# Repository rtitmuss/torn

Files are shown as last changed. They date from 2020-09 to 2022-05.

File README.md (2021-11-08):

Torn
===============

The split keyboard kit made with through hole components. The design has been inspired by the [Corne](https://github.com/foostan/crkbd), [Plaid](https://github.com/hsgw/plaid) and [Discipline](https://github.com/coseyfannitutti/discipline) keyboards.

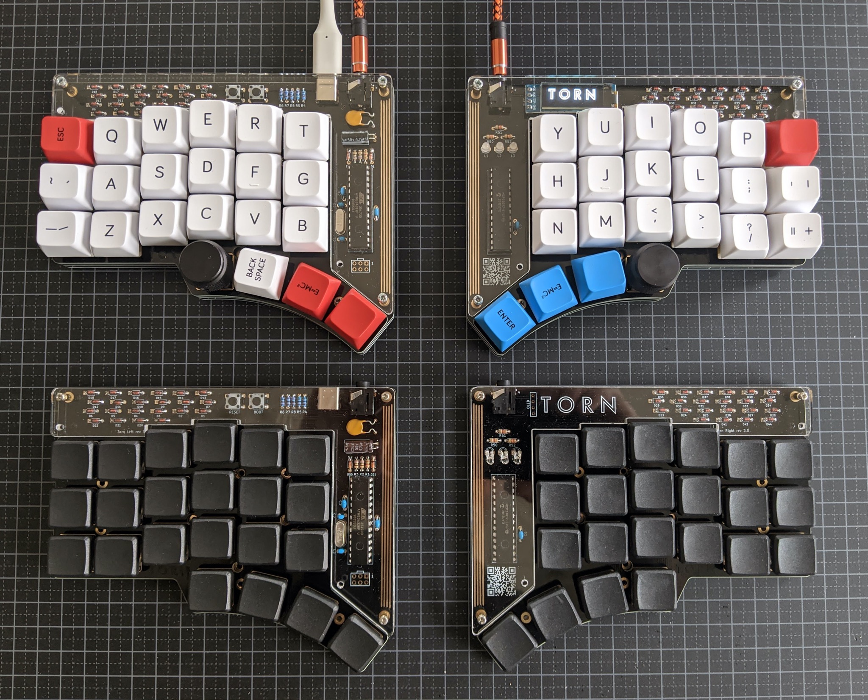
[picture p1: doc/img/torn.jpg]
torn


Torn uses an Atmega328P cpu, running QMK with VUSB:
- [QMK firmware](https://github.com/qmk/qmk_firmware/blob/master/keyboards/torn/readme.md).
- [Bootloader](https://github.com/rtitmuss/USBaspLoader).
- Compatible with [VIA](https://caniusevia.com/)

## Building your own Torn keyboard

Later this year you will be able to buy a Torn keyboard kit from [splitkb.com](https://blog.splitkb.com/blog/january-2021).
Alternatively you can also buy [all the parts](./doc/bom.md) needed youself.

Instructions are in the [Build guide](./doc/build.md) and [Troubleshooting guide](./doc/troubleshoot.md).
You can ask questions and get help on the [Torn Discord channel](https://discord.gg/mamAqNccju).

There is also a detailed [build log](https://github.com/rafaeldelboni/buildlogs/blob/main/torn-v3.md)
and [video](https://www.youtube.com/watch?v=7WUTQ30Datw). Thanks [rafaeldelboni](https://github.com/rafaeldelboni)! 

## Thanks

It would not have been possible for me to design Torn without the information and designs published by the mechanical keyboard community. So thanks go to ...

### Guides

* [Corne Keyboard build log](https://thomasbaart.nl/2018/11/26/corne-keyboard-helidox-build-log/) was my first step into this rabbit hole ...
* [Keyboard PCB Guide](https://github.com/ruiqimao/keyboard-pcb-guide) a beginners guide to designing a keyboard PCB in KiCad
* [Guide: Keyboard Construction Explained](https://brianlee.blog/2018/11/23/guide-keyboard-construction-explained/)
* [Cheat sheet: Custom keyboard mounting styles](https://thomasbaart.nl/2019/04/07/cheat-sheet-custom-keyboard-mounting-styles/)

### PCB Design

* [KiCad](https://kicad.org/) for PCB design
* [Split keyboard comparison site](https://jhelvy.shinyapps.io/splitkbcompare/) to iterate on key layout
* [Keyboard layout editor](http://www.keyboard-layout-editor.com/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,%3B&@_y:-0.875&x:2%3B&=X&_x:1%3B&=V&_x:5%3B&=M&_x:1%3B&=.%3B&@_y:-0.875&x:5%3B&=B&_x:3%3B&=N%3B&@_y:-0.875&a:7%3B&=&_a:4%3B&=Z&_x:11&a:7%3B&=&=%3B&@_y:-0.2749999999999999&x:3%3B&=&_x:7%3B&=%3B&@_r:13&rx:3.5&ry:8.5&y:-5.4&x:-0.5%3B&=%3B&@_r:26&y:-1&x:-0.5%3B&=%3B&@_r:39&y:-1&x:-0.5%3B&=%3B&@_r:-39&rx:11.5&y:-5.4&x:-0.5%3B&=%3B&@_r:-26&y:-1&x:-0.5%3B&=%3B&@_r:-13&y:-1&x:-0.5%3B&=) for your layout
* [Plate & Case Builder](http://builder.swillkb.com/) Generate CAD files from KLE files
* [keyswitches.pretty](https://github.com/daprice/keyswitches.pretty) KiCad library of mechanical keyboard switch footprints 

### QMK Firmware

* [QMK](https://docs.qmk.fm/#/) Quantum Mechanical Keyboard firmware
* [REMAP](https://remap-keys.app/) to easily configure your keyboard online
* [VIA](https://caniusevia.com/) to configure your keyboard

### 3d Design

The following are great resources to get started with keyboard case design:

* [Fusion 360](https://www.autodesk.com/products/fusion-360/personal)
* [65% Keyboard Case Design](https://youtu.be/4P0zfLLblOw)
* [Hinged Box for 3D Printing](https://youtu.be/iSBsBTMsGTk)
* [Snap Fit Cases](https://www.youtube.com/watch?v=E0NVC8xhf3I)
* [Knurling for 3D Printing](https://www.youtube.com/watch?v=jKPbye0XtMk)

### Other Keyboards

I took inspiration from other keyboards I'd used or liked:

* [Kinesis Advantage](https://kinesis-ergo.com/shop/advantage2/) my daily driver and endgame for almost 20 years! Opps! 
* [Corne](https://github.com/foostan/crkbd)
* [Discipline](https://github.com/coseyfannitutti/discipline) (used with permission from [coseyfannitutti](https://github.com/coseyfannitutti/))
* [Plaid](https://github.com/hsgw/plaid)
* [Lily](https://docs-gitbook.keeb.io/docs/iris-rev3-build-guide)
* [Dactyl](https://raw.githubusercontent.com/adereth/dactyl-keyboard/master/guide/circuit-diagram.png)

## License



The Torn Keyboard is licensed under [Creative Commons Attribution-NonCommercial 4.0 International License](https://creativecommons.org/licenses/by-nc/4.0).

This PCB design may be freely reproduced, modified, and manufactured for personal use only. If you would like to use this design commercially please contact me at richard.titmuss@gmail.com to request permission.
 
## Gallery

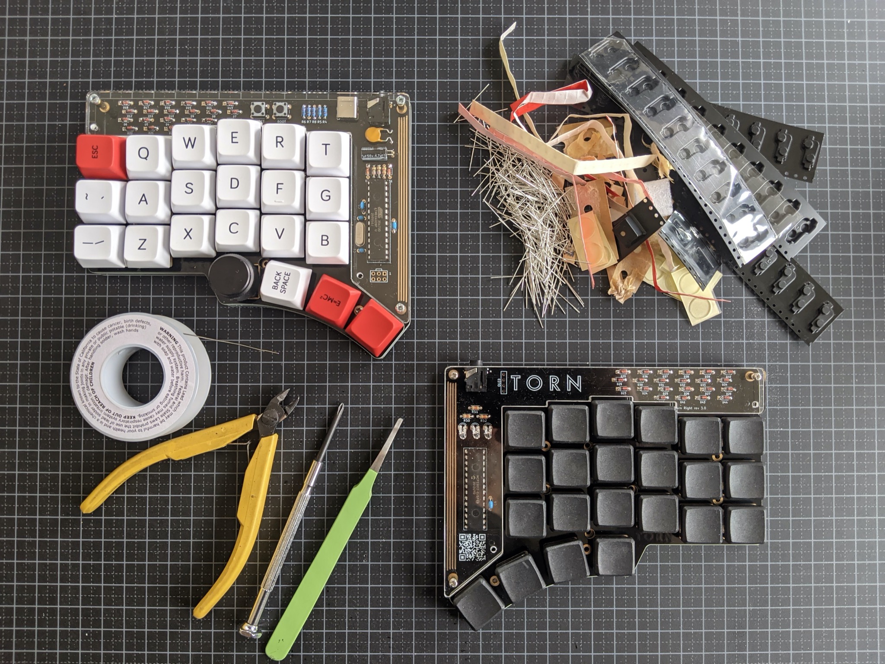
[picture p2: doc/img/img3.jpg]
Build Photo


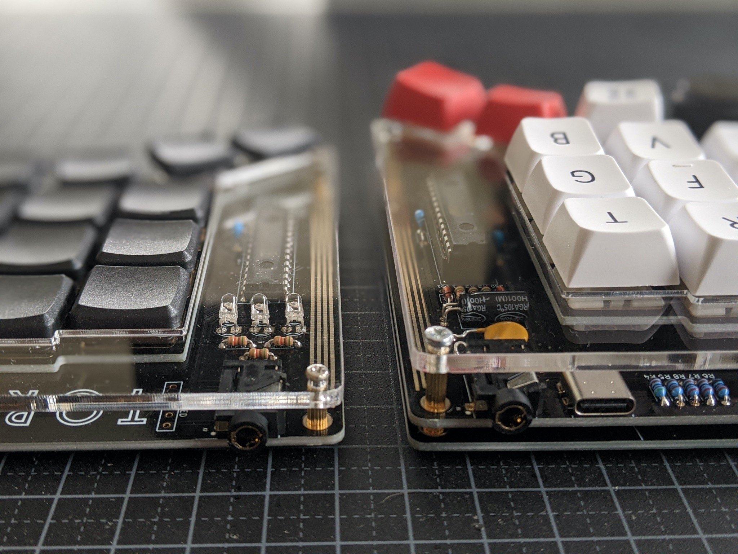
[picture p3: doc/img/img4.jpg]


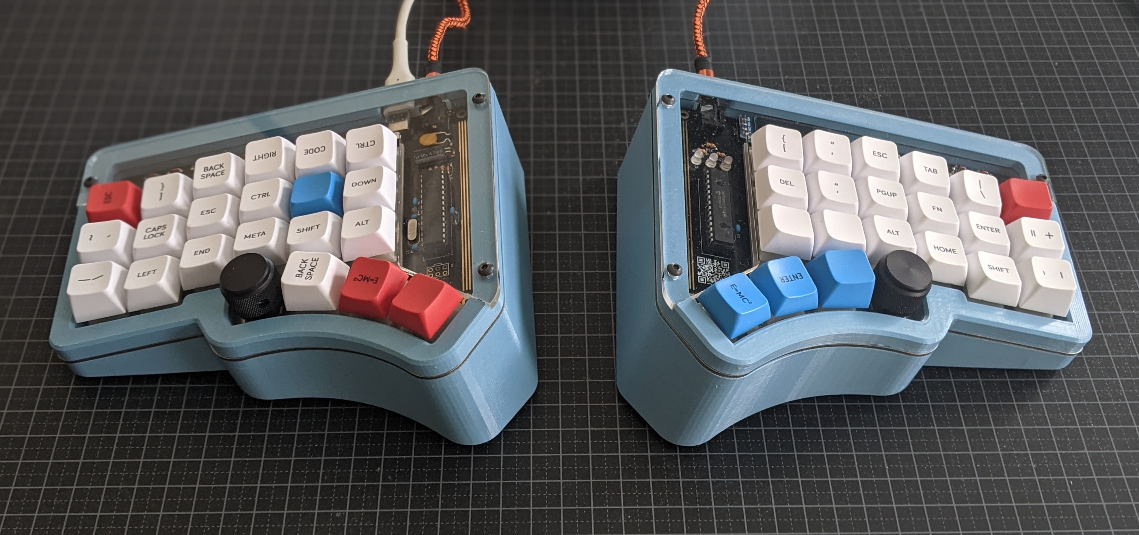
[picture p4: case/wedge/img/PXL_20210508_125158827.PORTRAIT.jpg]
Wedge Case


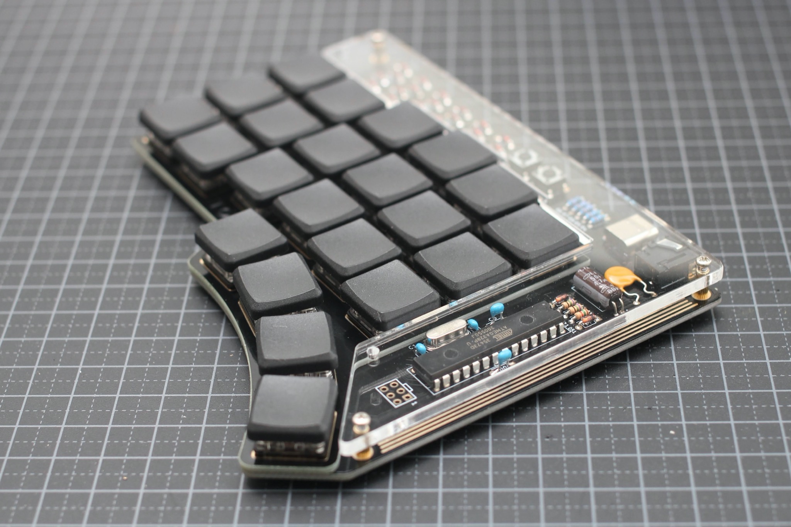
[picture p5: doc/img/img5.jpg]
Choc Switches


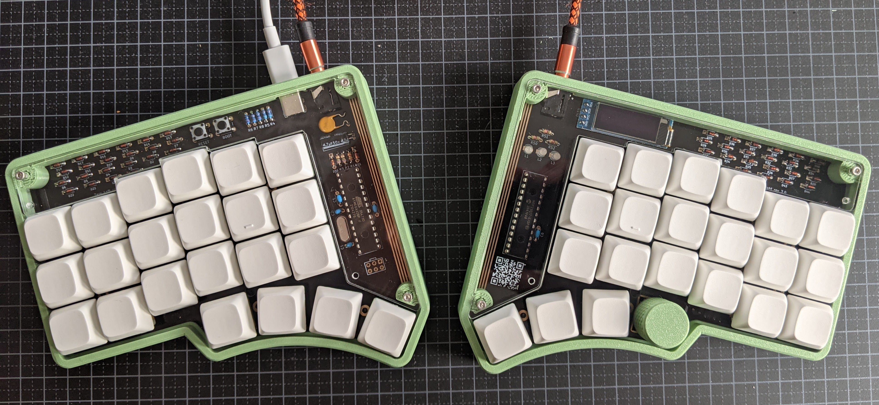
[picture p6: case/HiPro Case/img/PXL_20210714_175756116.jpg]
HiPro Case


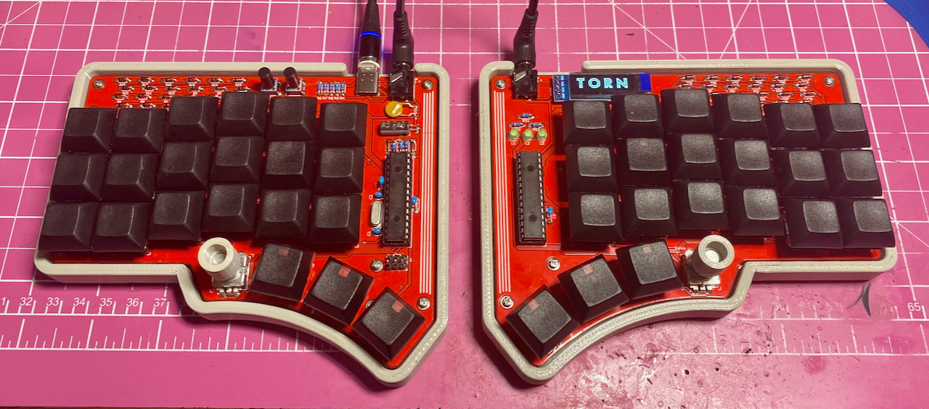
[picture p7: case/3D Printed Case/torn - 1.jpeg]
3d Case


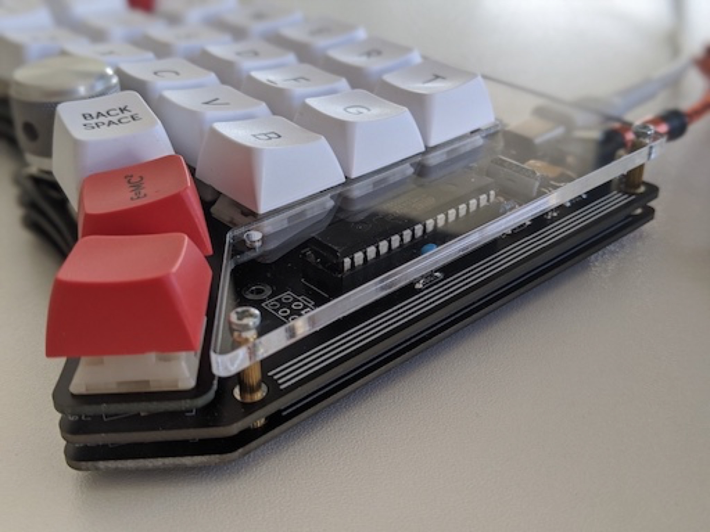
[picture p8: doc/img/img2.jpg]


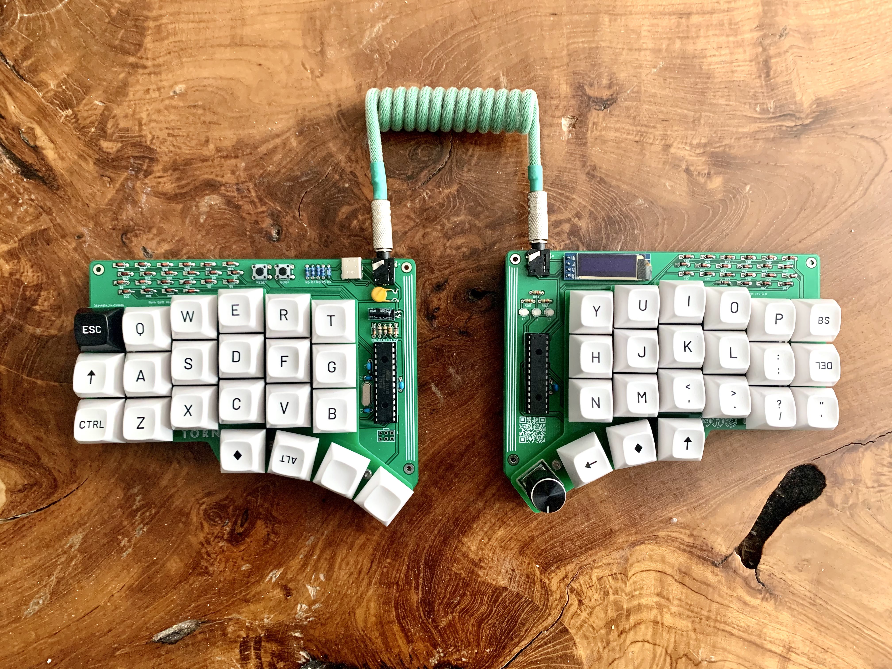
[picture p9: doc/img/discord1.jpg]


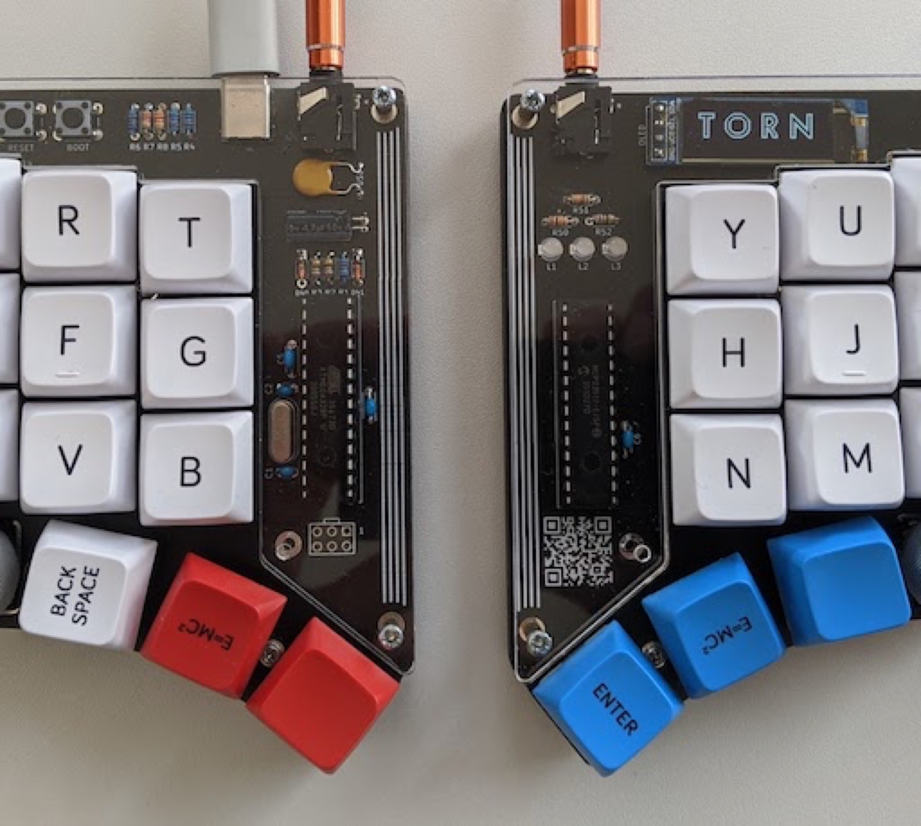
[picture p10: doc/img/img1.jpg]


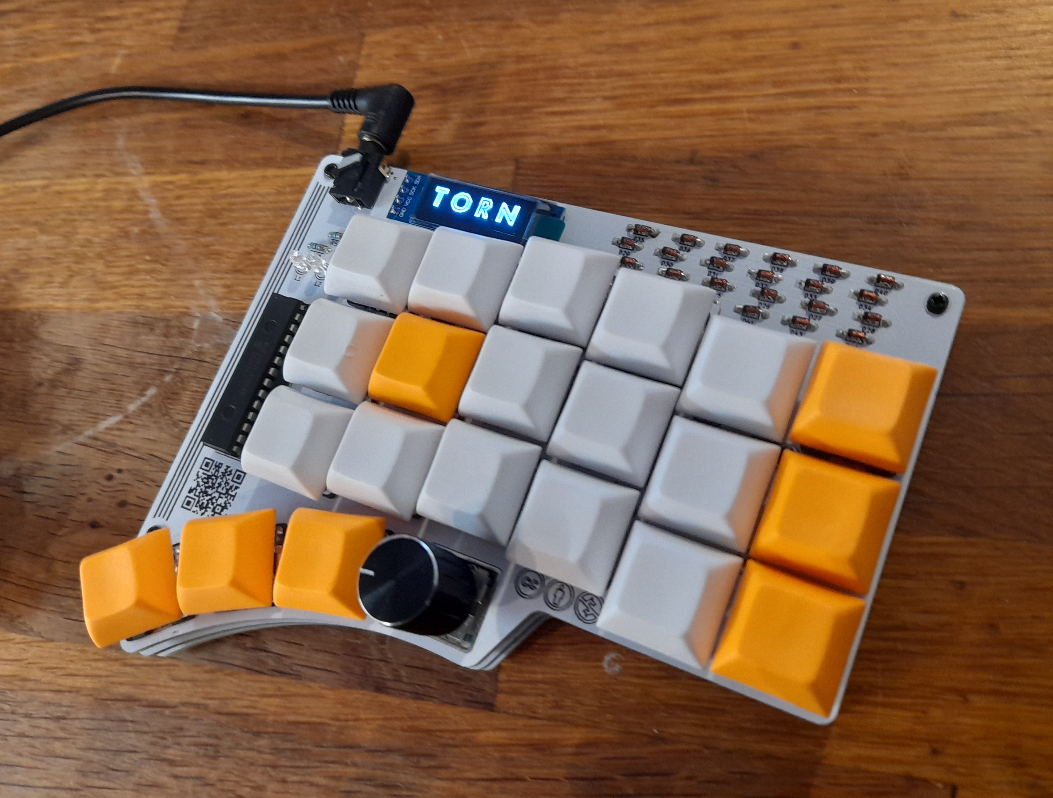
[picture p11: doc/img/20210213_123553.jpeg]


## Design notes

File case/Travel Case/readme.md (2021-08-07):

# Torn Travel Case

This 3D printed travel case is designed for Kailh Choc switches, featuring a print in place hinge
with internal wiring.

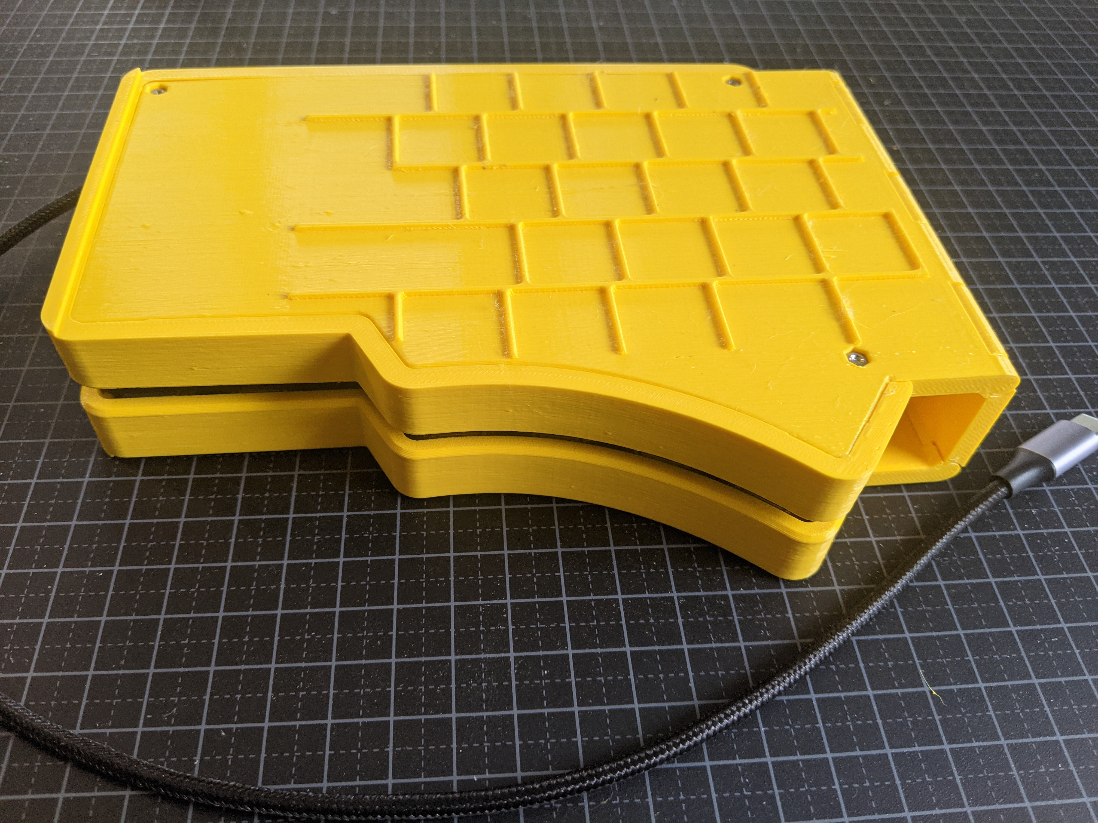
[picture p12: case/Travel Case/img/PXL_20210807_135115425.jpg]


There are two versions of this case.  The version designed to be used with a 15 inch 2017 Macbook Pro
and features integrated cable routing and a guide to position the case over the Macbook keyboard.

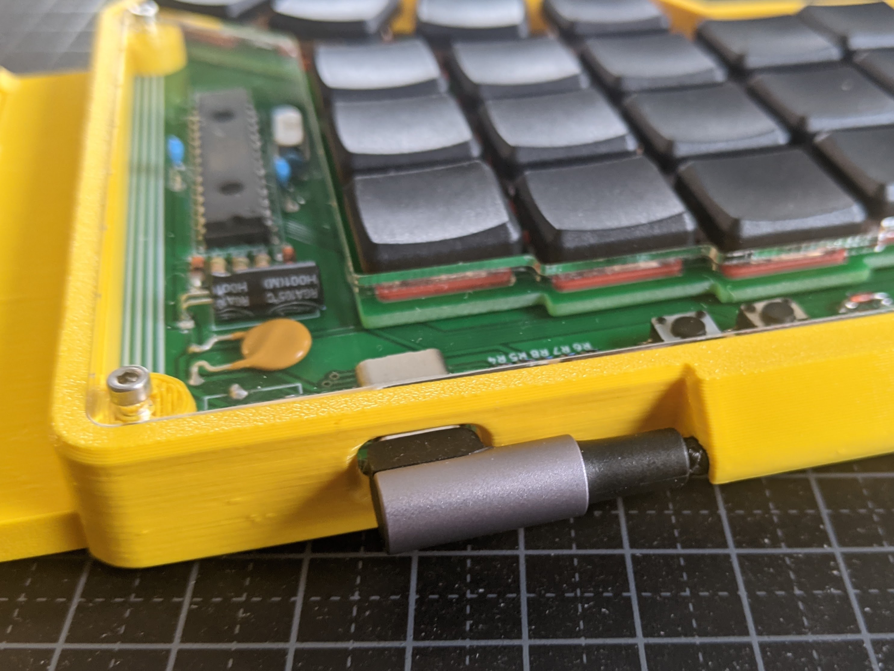
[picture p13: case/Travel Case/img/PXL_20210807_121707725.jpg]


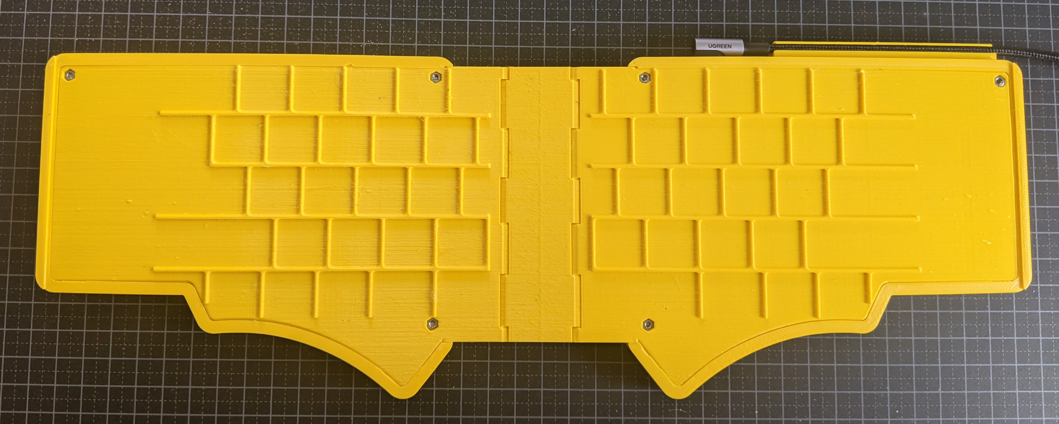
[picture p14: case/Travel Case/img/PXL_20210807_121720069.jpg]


The basic version is a folding travel case without the cable routing and key guides.

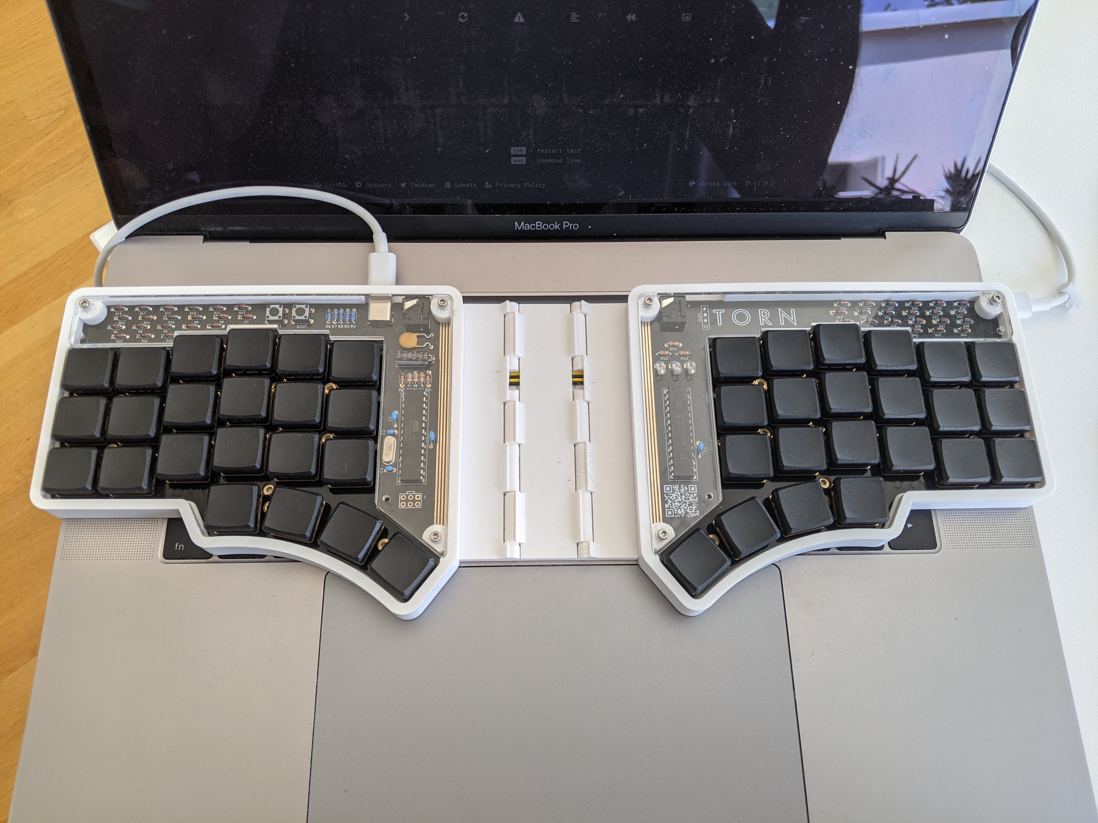
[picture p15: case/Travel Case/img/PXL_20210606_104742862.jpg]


## Parts

To complete the Travel Case you need:

- Assembled Torn PCBs with Kailh Choc switches (but see notes below)
- 3d printed parts using the STLs below
- 4 wires
- 2 x acrylic covers
- 6 x m2 nuts
- 6 x m2 x 12mm cheese head screws
- UGREEN USB C to USB C Cable _Right Angle 90 Degree_ (optional, for Macbook case)

## STLs

This case has been tested with a Prusa i3 Mk3S+ using PTEG. The parts are designed to be a tight fit
so tolerances may vary with other printers or plastics. The parts are available in STL or 3MF. You
can use the 3MF files in [PrusaSlicer](https://www.prusa3d.com/prusaslicer/) and they contain the
recommended print settings.

You need to 3d print the following parts for the basic travel case:

- Base [STL](./stl/Base%20basic.stl)
- Left Top [STL](./stl/Left%20basic.stl)
- Right Top [STL](./stl/Right%20basic.stl)

The 15 inch 2017 Macbook Pro version needs:

- Macbook Pro Base [STL](./stl/Base%20macbook.stl) [3MF](./stl/Base%20macbook.3mf)
- Macbook Pro Left Top [STL](./stl/Left%20macbook.stl) [3MF](./stl/Left%20macbook.3mf)
- Macbook Pro Right Top [STL](./stl/Right%20macbook.stl) [3MF](./stl/Right%20macbook.3mf)

_You do not need to change the orientation of the files on the print bed. Do not use supports for
the base_. The base prints vertically as shown in the picture below. To improve the print quality
make sure the seams are not near the hinged joints. After the base is printed you need to carefully
open the hinges. Do not use too much force or the hinges may break. Once free open and close the
hinges a few times until they move smoothly. 

The left and right tops need printing with supports. Carefully remove all the support material from
the case tops. Test that the acrylic cover fits flush with the edge of the case.

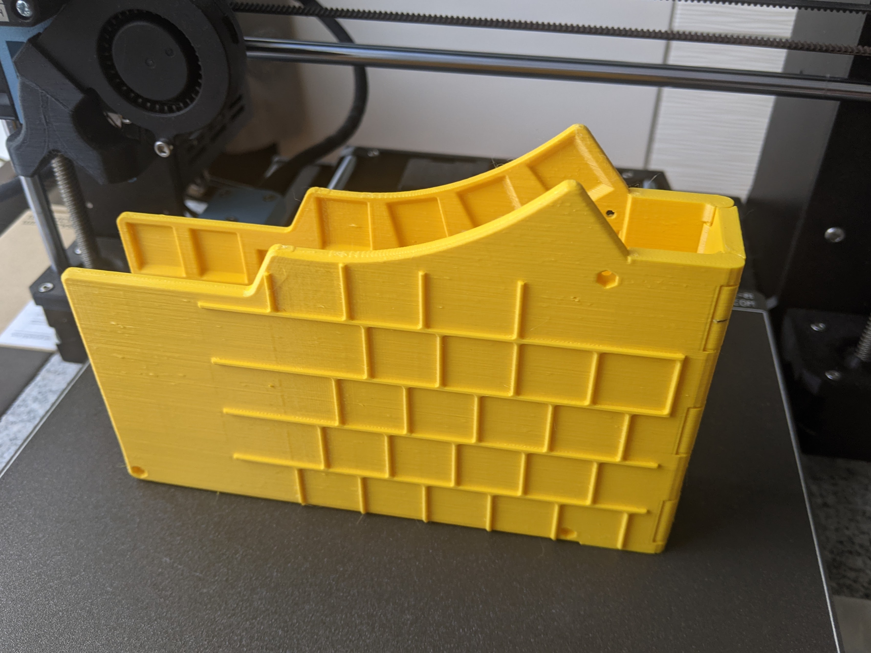
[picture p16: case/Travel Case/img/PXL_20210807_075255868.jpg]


## Build guide

Before assembling the Choc Case you need to have assembled the [Torn PCBs](../../doc/pcb.md).

**Do not use the IC sockets (steps 13 and 22 in the main instructions). The ATMega328P and MCP23017 
must be directly soldered to the PCB. This is needed to reduce the height. You also don't need to
install the TRRS sockets (steps 12 and 21 in the main instructions) as the case includes internal
wiring.**

## Step 1

Place the pcb plate on the main pcb, and insert a few Choc switches. Make sure everything fits
correctly. Then add the remaining switches.

## Step 2

Check that the switches are all inserted correctly, then solder the switches. Complete Step 1 and
Step 2 for both the left and right sides before proceeding.

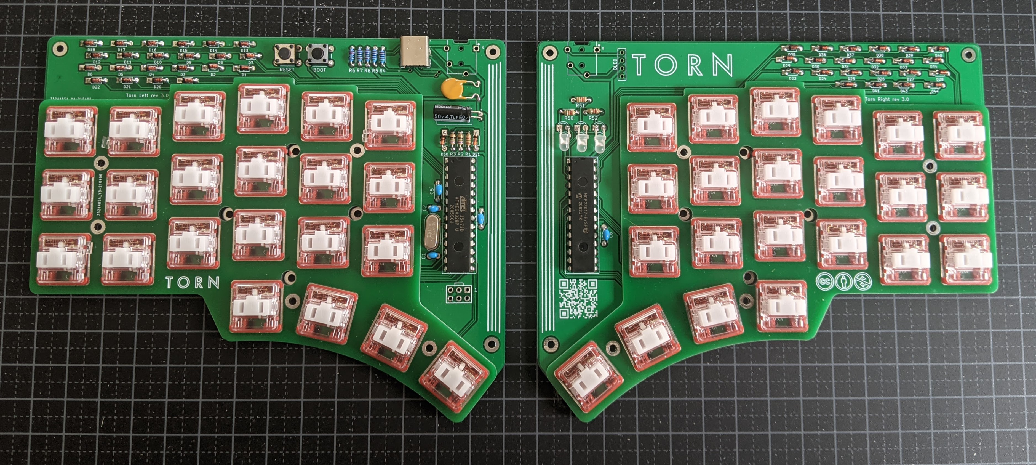
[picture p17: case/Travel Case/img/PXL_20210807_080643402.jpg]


## Step 3

Insert six m2 nuts in the base of the case. Tighten an m2 screw to pull the nuts securely into the
base. Remove the screw afterwards.

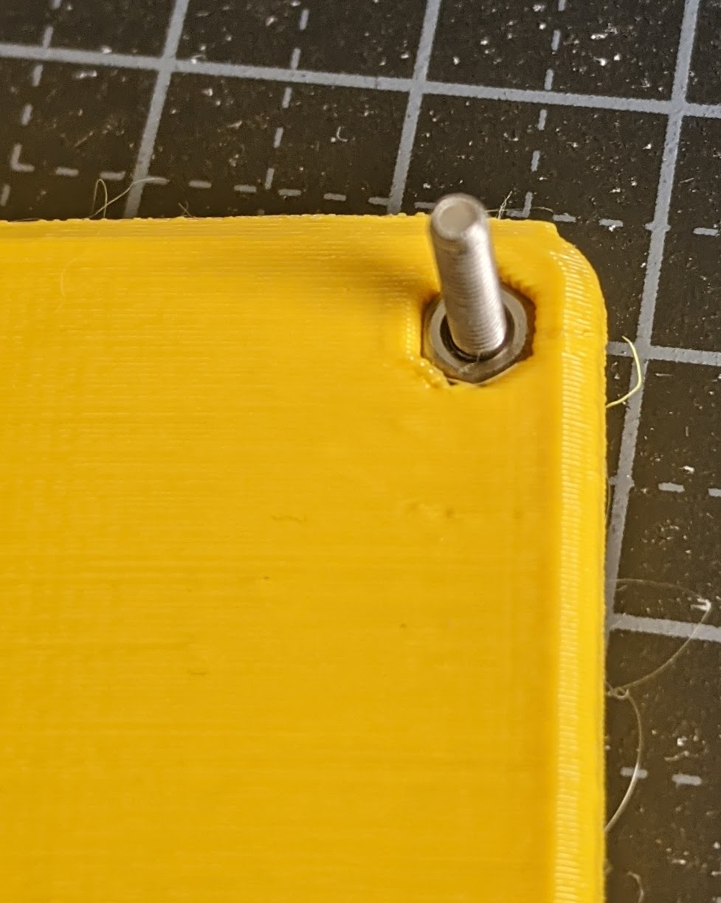
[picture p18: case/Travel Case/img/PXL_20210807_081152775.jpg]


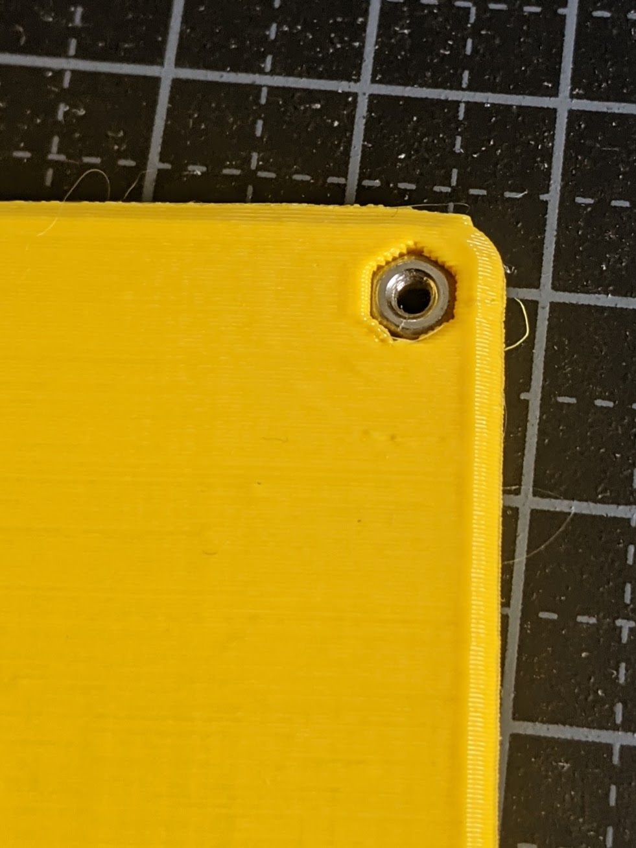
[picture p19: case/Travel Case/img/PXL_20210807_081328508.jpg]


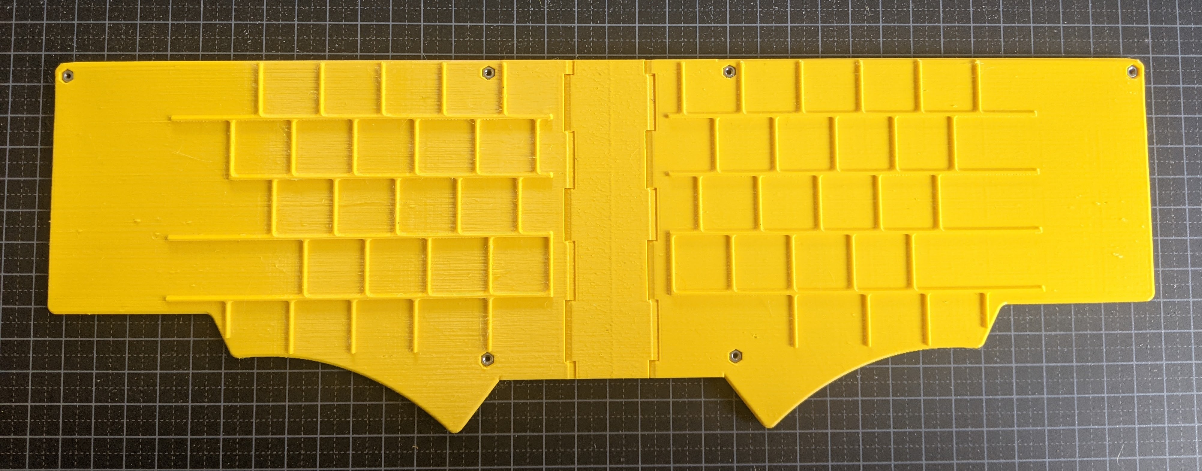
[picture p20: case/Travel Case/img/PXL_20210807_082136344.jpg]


## Step 4

Solder four wires to the TRRS pins on the left pcb. The wires should be on the underside of the
pcb. There is little clearance in the case for the wires, so it is important to arrange them as
shown in the pciture below.

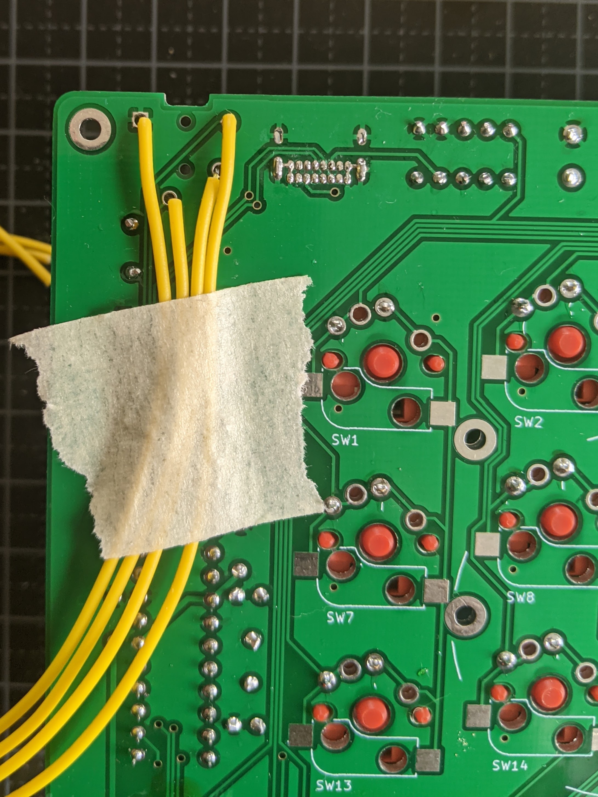
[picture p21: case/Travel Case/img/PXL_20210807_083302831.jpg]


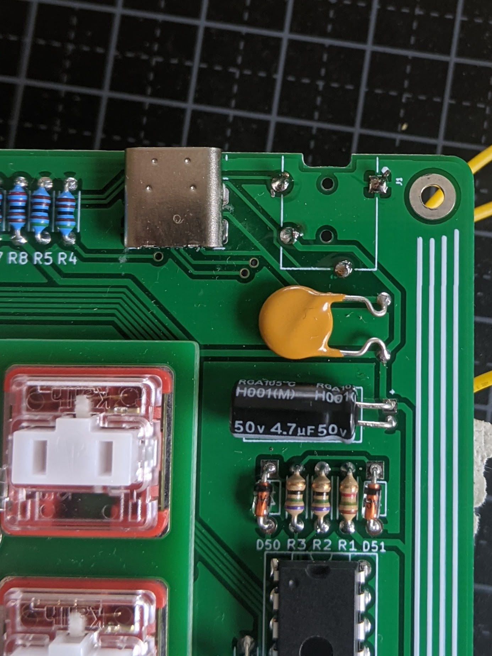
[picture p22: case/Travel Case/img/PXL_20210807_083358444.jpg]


## Step 5

Insert the completed left pcb in the top left of the case.

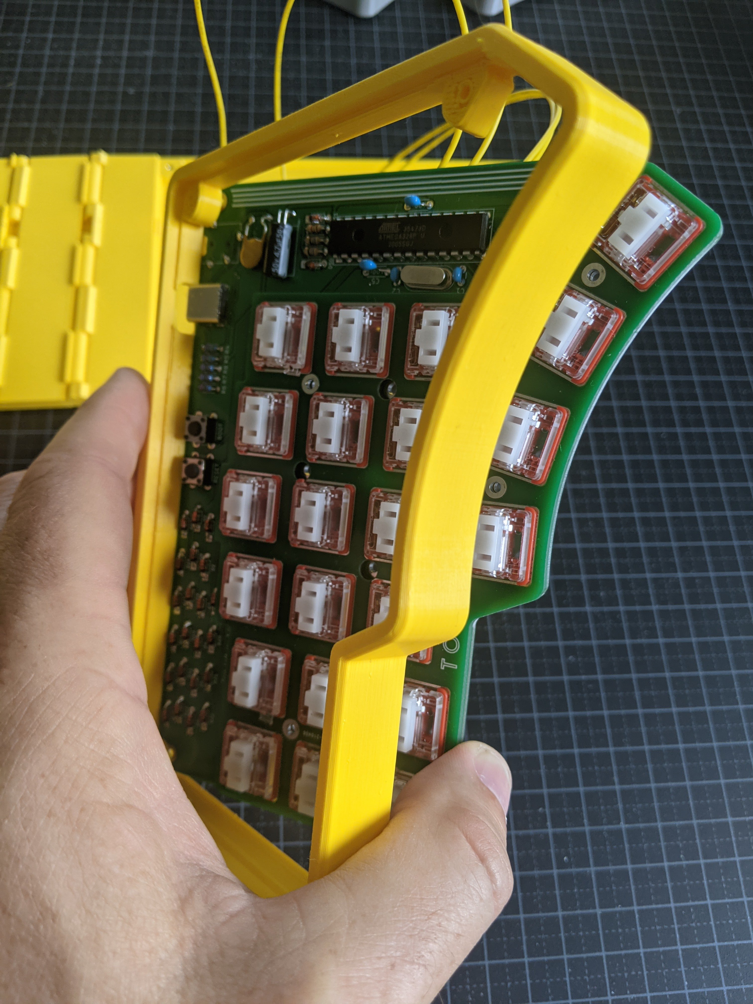
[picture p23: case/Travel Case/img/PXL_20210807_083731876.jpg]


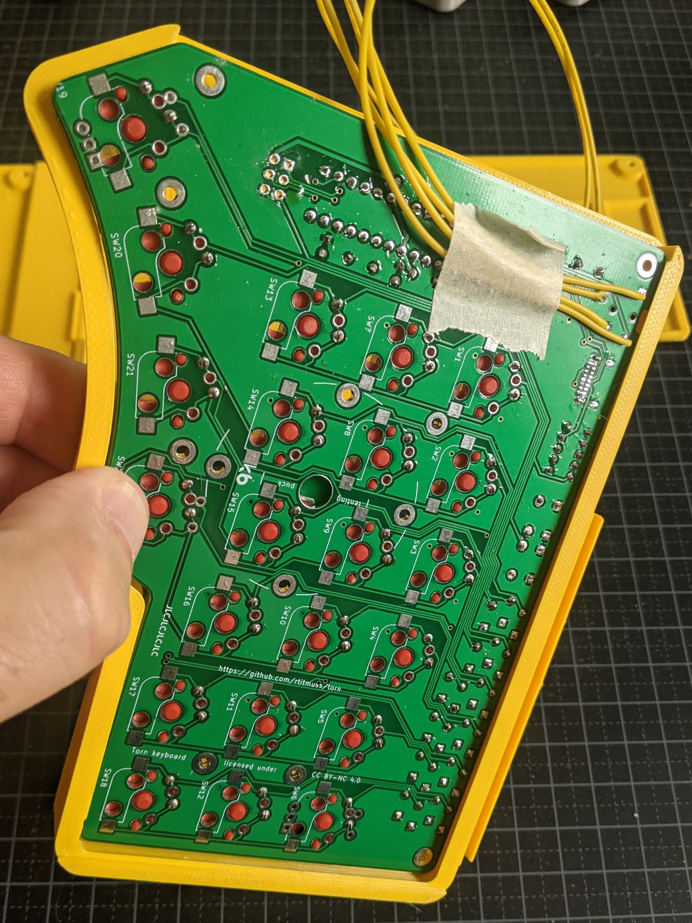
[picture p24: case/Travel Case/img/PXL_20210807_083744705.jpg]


## Step 6

Carefully feed the wires through the hinge. Remember there is little clearance in the case underneath
the pcb so _the wires must not cross_. Use the pictures below for reference.

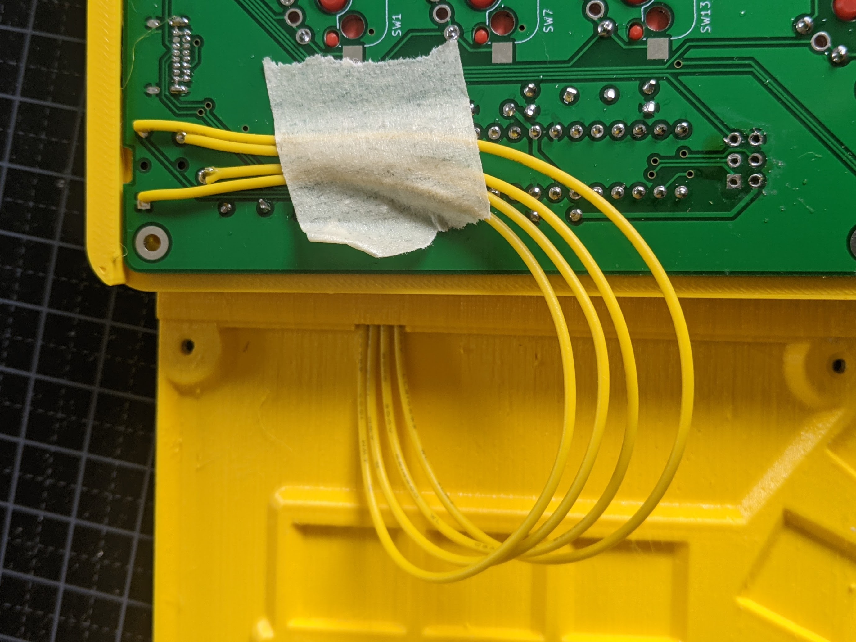
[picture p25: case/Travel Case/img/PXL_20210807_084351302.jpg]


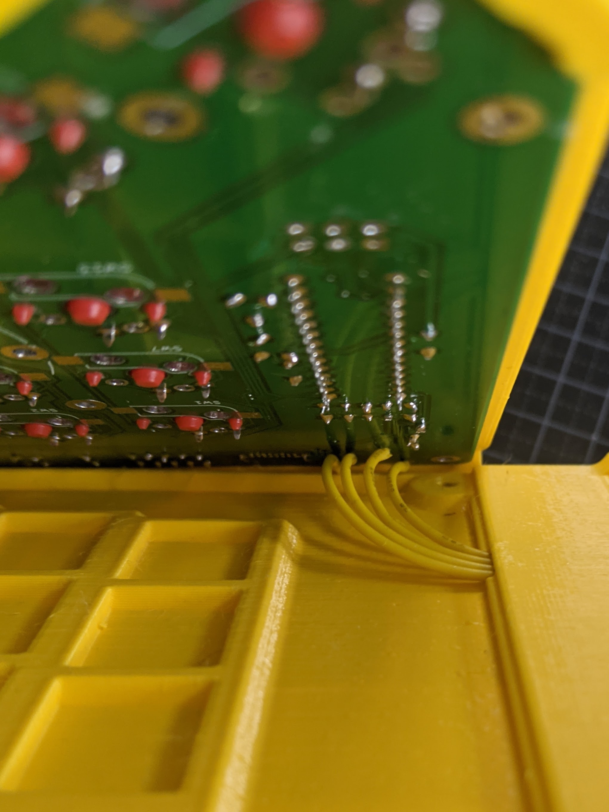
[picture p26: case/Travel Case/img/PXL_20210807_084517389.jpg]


## Step 7

Assemble the left side the case. This is a snap fit, so work around the edges until the case is
completely closed. Check that the wires are not trapped, and that the hinge works smoothly.

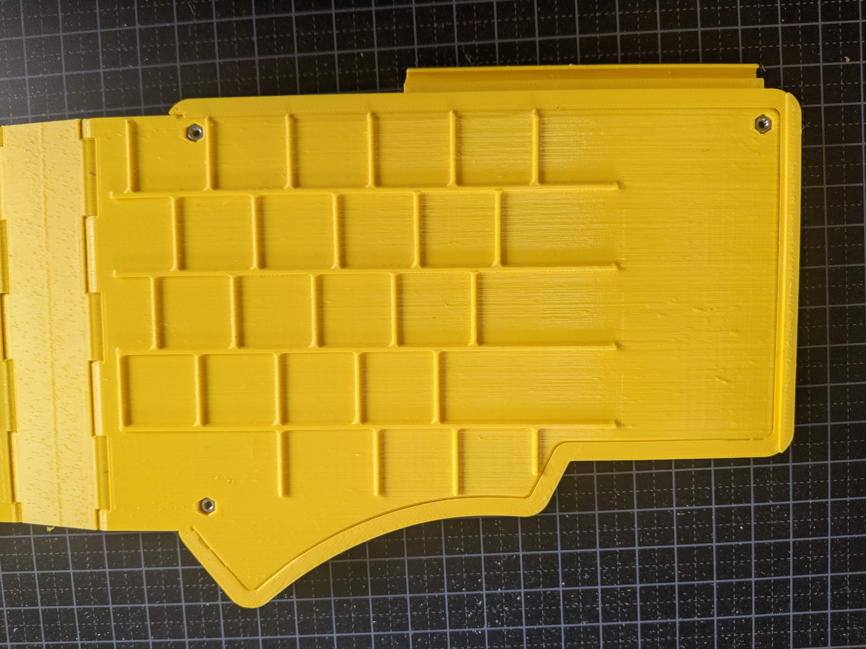
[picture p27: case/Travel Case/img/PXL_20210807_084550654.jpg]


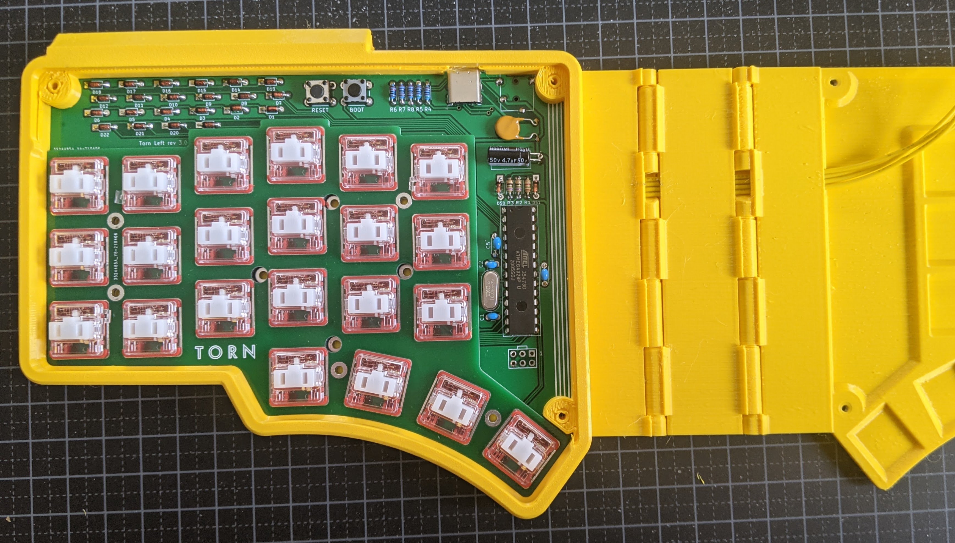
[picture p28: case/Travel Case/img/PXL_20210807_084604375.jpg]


## Step 8

The wires need to be cut to the correct length. You can do this be bending the wires as shown below
and cutting inline with the top edge of the case. Strip the ends of the wires and tin them.

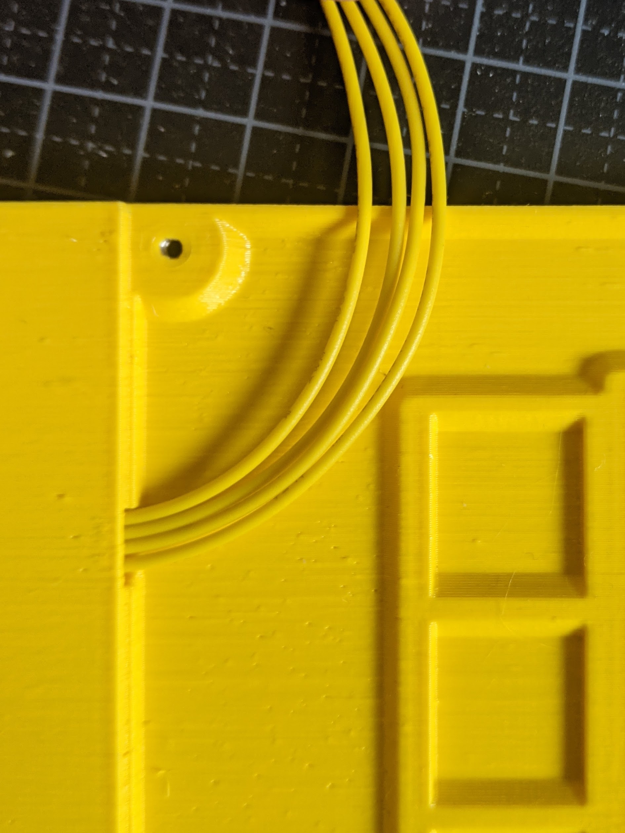
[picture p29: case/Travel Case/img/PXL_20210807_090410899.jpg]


## Step 9

This step is fiddly, take your time. Solder the four wires to the right pcb as follows and shown in
the photo below. Take care with the wire routing, remember there is little clearance and the wires
must not cross.

- Top wire is GND, connect this to the TRRS port pin 1 (marked with a dot on the top silk screen).

- 2nd wire is I2C_SCL, connect this to the 2nd OLED pin (counting from the pcb edge).

- 3rd wire is VCC, connect this to the 3rd OLED pin.

- Bottom wire is I2C_SCK, connect this to the 1st OLED pin.

You can solder the wires from the top of the PCB.

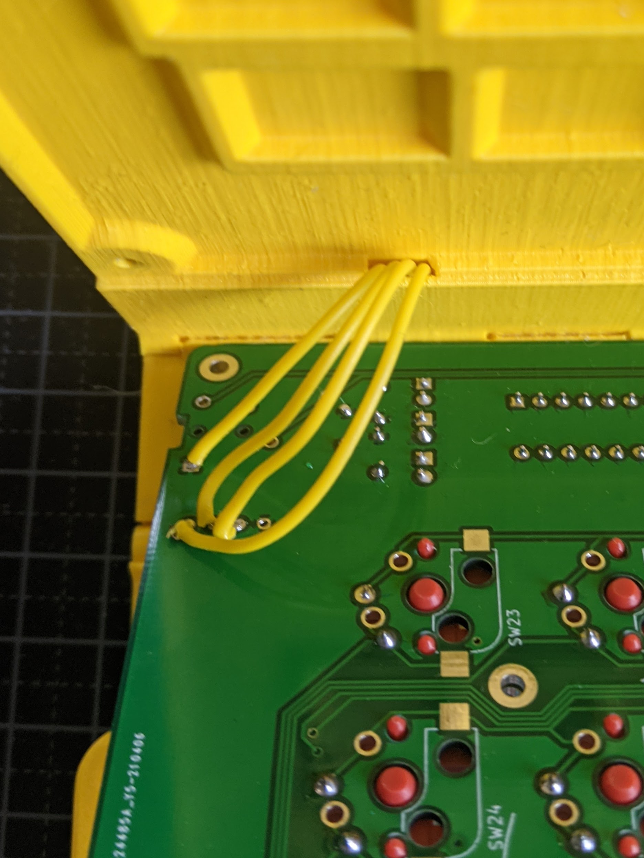
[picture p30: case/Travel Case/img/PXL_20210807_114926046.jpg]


## Step 10

Insert the right pcb in the top right of the case and assemble the case. This is a snap fit, so work
around the edges until the case is completely closed. Check that the wires are not trapped, and that
the hinge works smoothly.



## Step 11

Double check the TRRS wiring. You can do this with a multimeter set to test the continuity.

| ATmega328P | MCP23017 | Signal  |
| --- | --- | ---  |
| Pin 7 | Pin 9 | VCC |
| Pin 8 | Pin 10 | GND |
| Pin 28 | Pin 12 | I2C_SCL |
| Pin 27 | Pin 13 | I2C_SDA |

You can refer to the [troubleshooting guide](../../doc/troubleshoot.md) to see the pinouts.

## Step 12

Add the acrylic covers and secure with six 12mm m2 screws. Fit the keycaps and USB cable. Enjoy!

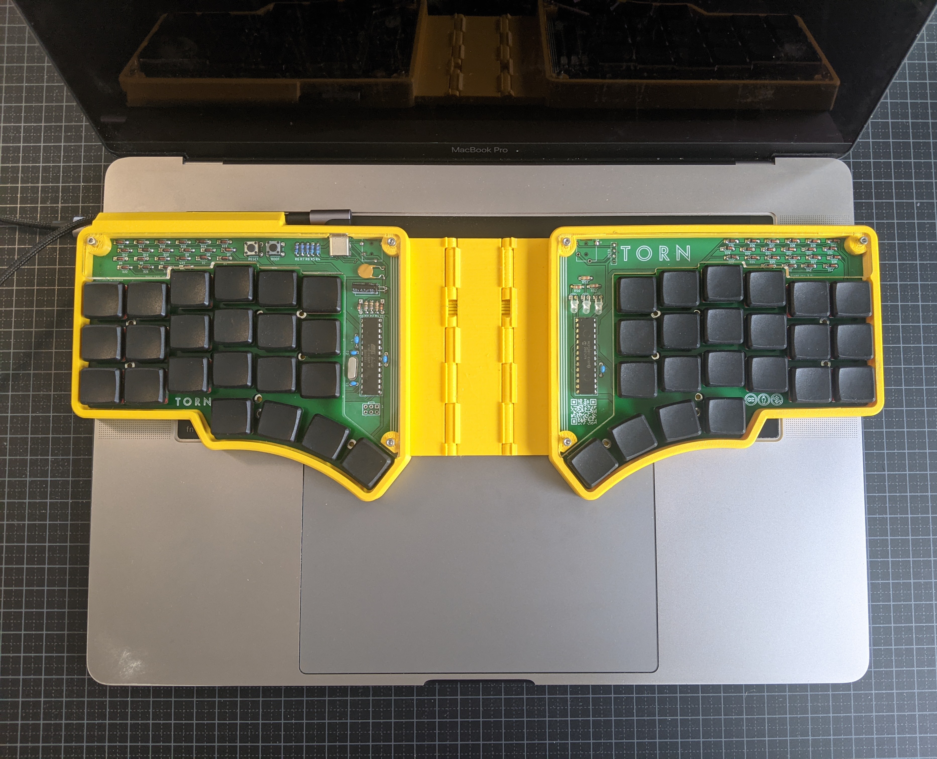
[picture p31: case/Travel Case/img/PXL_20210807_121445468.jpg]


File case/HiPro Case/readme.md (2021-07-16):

# Weighted HiPro Case

This 3d printed Weighted HiPro Case is designed for MX or Kailh Choc switches. This case is designed
with a snap fit assembly, and to include 200g weight in each half.

You can print your own case using the files below or buy one from me! The cases are printed on demand
and can be made in a color of your choice, it is even possible to try and match the color to your keycaps.
Prices start from €60 plus shipping from Europe. If your interested please contact me at
richard.titmuss@gmail.com or on [Discord](https://discordapp.com/users/745293992044003348/) for more
information.

**MX Case**



**Choc Case**

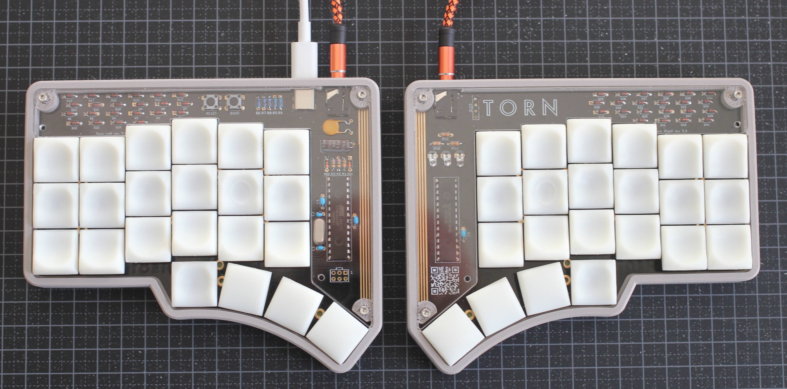
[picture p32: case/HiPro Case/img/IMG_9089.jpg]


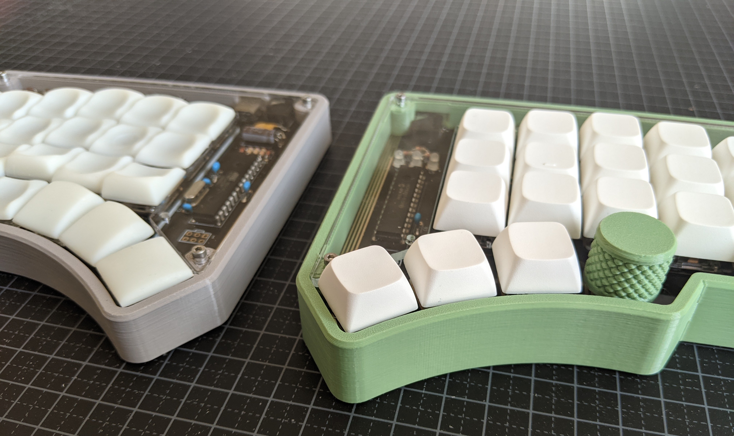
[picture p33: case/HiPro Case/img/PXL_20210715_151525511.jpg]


## Parts

To complete the Weighted HiPro Case you need:

- Assembled Torn PCBs with MX or Kailh Choc switches
- 3d printed parts using the STLs below
- 2 x Torn acrylic covers
- 6 x m2 nuts
- 6 x m2 x 20mm cheese head screws (MX switches)
- 6 x m2 x 16mm cheese head screws (Choc switches)
- Car wheel balance weights. 10g: 23mm x 19mm. 5g: 12mm x 19mm. height 4mm (including adhesive padding).
For example:
[US](https://www.amazon.com/Pit-Posse-Balancing-Weights-Adhesive/dp/B00OQWS98S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),
[UK](https://www.amazon.co.uk/FIERCE-CYCLE-Balance-Weights-Motorcycle/dp/B07QQ539GV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),
[SE](https://www.amazon.se/gp/product/B01GHKG18G/ref=ppx_yo_dt_b_asin_image_o00_s00?ie=UTF8&psc=1).

## STLs

This case has been tested with a Prusa i3 Mk3S+ using PTEG. The parts are designed to be a tight fit
so tolerances may vary with other printers or plastics. The parts are available in STL or 3MF. You
can use the 3MF files in [PrusaSlicer](https://www.prusa3d.com/prusaslicer/) and they contain the
recommended print settings.

You need to 3d print the following parts:

### Base (MX and Choc switches)

- Left Base [STL](./stl/Left%20base.stl) [3MF](./stl/Left%20base.3mf)
- Right Base [STL](./stl/Right%20base.stl) [3MF](./stl/Right%20base.3mf)

Print Settings: **No supports. 15% infill. 135 degree bridging angle.**

The 3MF files include a color change for the Torn logo on the base. First load the color for the logo,
and then change to the case color after the letters have printed
([using this technique](https://forum.prusaprinters.org/forum/prusaslicer/manual-multicolor/)).
The STL files use bridging for a debossing effect.

### Top (MX switches)

- MX Left Top [STL](./stl/Left%20MX%20top.stl) [3MF](./stl/Left%20MX%20top.3mf)
- MX Right Top [STL](./stl/Right%20MX%20top.stl) [3MF](./stl/Right%20MX%20top.3mf)

This part prints upside down (the STL is oriented for printing). Supports are needed on the rim 
where the acrylic cover fits.

Print Settings: **Supports on build pate only. 15% infill.**

- MX Left Spacer [STL](./stl/Left%20MX%20Spacer.stl) [3MF](./stl/Left%20MX%20Spacer.3mf)
- MX Right Spacer [STL](./stl/Right%20MX%20Spacer.stl) [3MF](./stl/Right%20MX%20Spacer.3mf)

Print Settings: **No supports. 15% infill.**

### Top (Choc switches)

- Choc Left Top [STL](./stl/Left%20Choc%20top.stl) [3MF](./stl/Left%20Choc%20top.3mf)
- Choc Right Top [STL](./stl/Right%20Choc%20top.stl) [3MF](./stl/Right%20Choc%20top.3mf)

### Encoder Knob (optional)

You can use this encoder knob to color match with your case.

- EC11 Knob [STL](./stl/EC11%20Knob.stl)

Print Settings: **No supports. 15% infill.**

### License



The Torn Weighted HiPro Case is licensed under [Creative Commons Attribution-NonCommercial 4.0 International License](https://creativecommons.org/licenses/by-nc/4.0).

## Build guide

Before assembling the Weighted HiPro Case you need to have assembled the [Torn PCBs](../../doc/pcb.md).

**Choc Switches: Do not use the IC sockets (steps 13 and 22 in the main instructions). The ATMega328P and MCP23017 
must be directly soldered to the PCB. This is needed to reduce the height.**

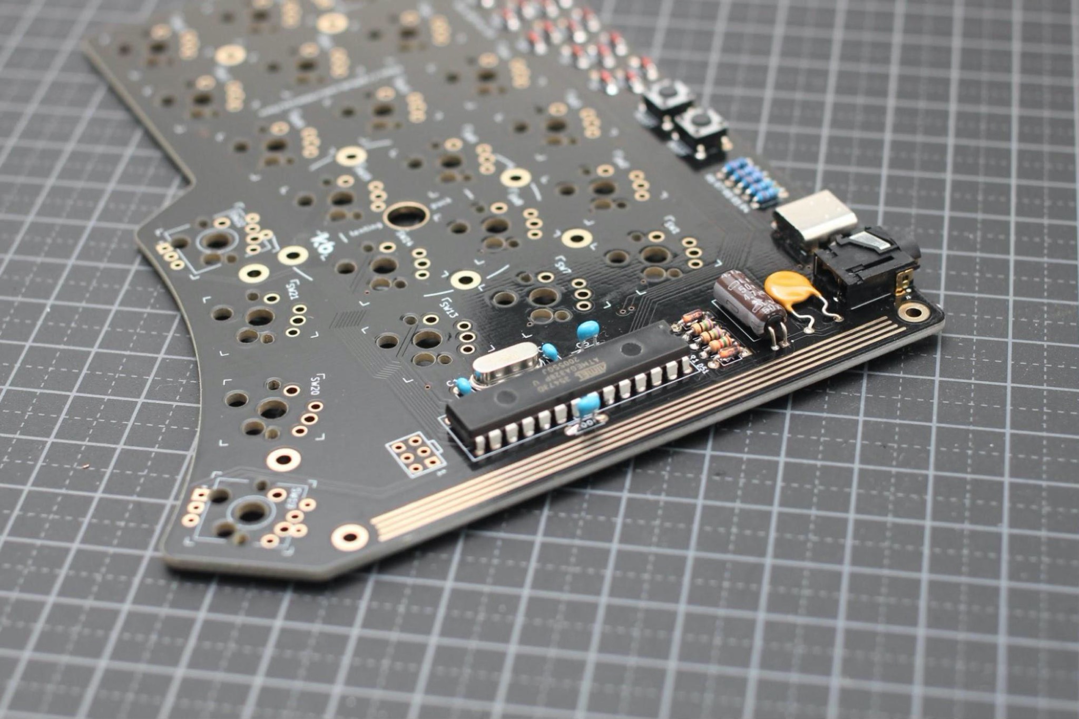
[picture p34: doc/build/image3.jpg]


Repeat steps 1-9 for the left and right sides of the keyboard.

### Step 1

Carefully remove *all* the support material from the case top. Test that the acrylic cover fits
flush with the edge of the case.

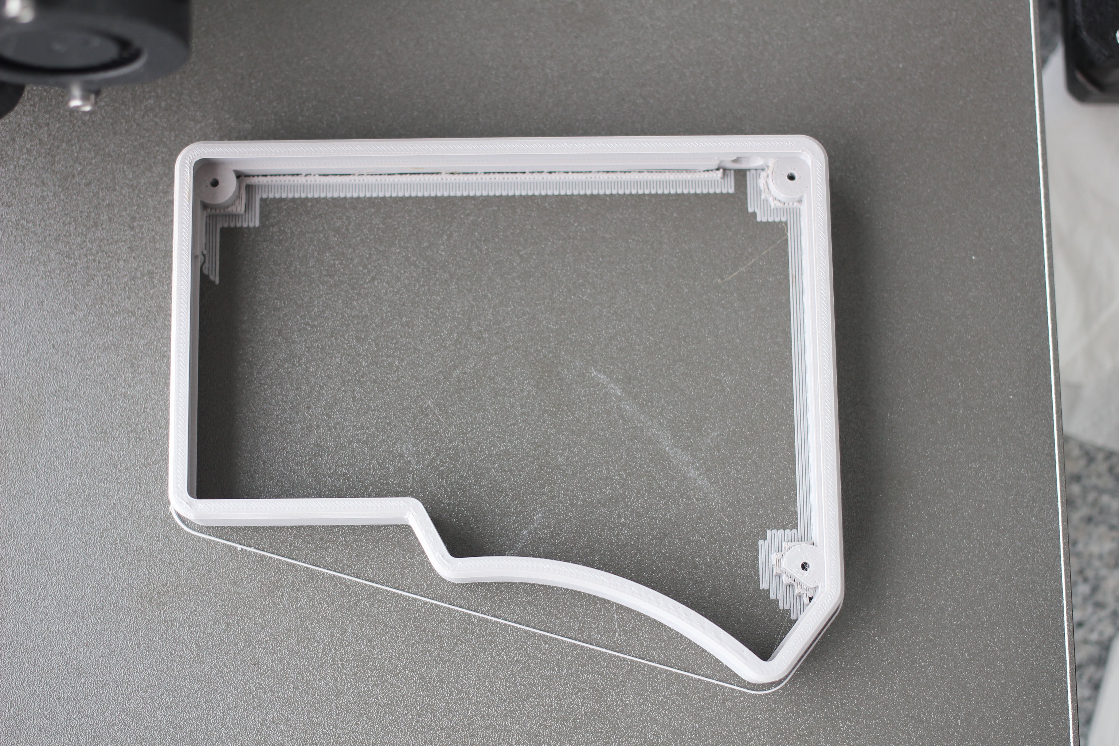
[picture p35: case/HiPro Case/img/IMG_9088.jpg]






### Step 2

Insert three m2 nuts in the base of the case. Use a m2 screw to pull the nuts securely into the
base. Remove the screw afterwards. 







### Step 3

Cut the car wheel balance weights to fit the case. Secure then with the self-adhesive padding. Be
neat, there is not any spare room! 





### Step 4 (MX switches only)

Assemble the spacer and plate. 





### Step 5

Insert a few switches in the plate, and assemble with the PCB. Make sure everything fits correctly,
and then add the remaining switches. Solder the switches (if you are not using Kailh MX sockets).

**Test that all the switches work before continuing.** You can take apart the case but this is not
easy with the snap fit assembly.







### Step 6

Insert the PCB into the top of the case. Start fitting the back edge as shown below. Make sure the
TRRS socket is in the correct place. Then carefully work around the edge of the case pressing the PCB
in place, ending by the thumb keys. You'll need to gently 'stretch' the top to get the PCB to fit.





### Step 7

Now insert the base into the top of the case. This is similar to the previous step, start with the
back edge as shown below. Then carefully work around the edge of the case pressing the PCB
in place, ending by the thumb keys. You'll need to gently 'stretch' the top to get the base to fit.

The case should feel secure once it is snapped together.





### Step 8

Add the acrylic cover. Secure with three m2 screws.



### Step 9

Finally add the keycaps.



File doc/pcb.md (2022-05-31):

# Torn PCB Assembly

These are the instructions to build the Torn PCB.

## Tools

You will need the following tools to complete the Torn Keyboard:

*   Soldering iron and solder wire (leaded solder recommended)
*   Flush side cutters
*   No-clean flux paste (recommended to prevent bridging on USB pins)
*   Desoldering wick and Solder sucker (recommended to fix any mistakes)

## What’s included

The following components are included in the Torn Keyboard kit:



Ref | Component | Notes
--- | --------- | -----
C1, C2 | ***2 x 22pF Capacitor***
C3 | ***1 x 4.7uF Capacitor***
C4, C5, C6 | ***3 x 0.1uF Capacitor***
D1-44 | ***44 x 1n4148 Diode***
D50, D51 | ***2 x 3.6V Zener Diode*** | Keep separate from the 1n4148 diodes!
F1 | ***1 x 500ms Resettable fuse*** |
ISP1 | **1 x 6 pin header***
J1, J2 | ***2 x TRRS socket***
L1, L2, L3 | ***3 x LED***
OLED1 | ***1 x OLED display***
R1 | ***1 x 1.5k Tan Resistor*** | ***Brown - Green - Red***
R2, R3 | ***2 x 75 Tan Resistor*** | ***Purple - Green - Black***
R6 | ***1 x  10k Blue Resistor*** | ***Brown - Black - Orange***
R4, R5 | ***2 x 5.1k Blue Resistor*** | ***Green - Brown - Red***
R7, R8 | ***2 x 2.2k Blue Resistor*** | ***Red - Red - Red***
R50-52 | ***3 x 5.1K Tan Resistor*** | ***Green - Brown - Red***
. | ***2 x 28 pin IC socket***
BOOT, RESET | ***2 x 6mm Push button***
U1 | ***1 x ATmega328P***
U2 | ***1 x I/O Expander***
USB1 | ***1 x USB4085 SB C port***
Y1 | ***1 x 16MHz Crystal***
. | ***10 x m2 3mm spacer***
. | ***6 x m2 8mm spacer***
. | ***16 x m2 3mm+3mm spacer***
. | ***6 x m2 5mm screw***
. | ***26 x m2 3mm screw***
. | ***8 x Feet***

## Build Guide

Let’s start building, all the parts ready:



While building the keyboard you can use the interactive BOM for the [left](https://htmlpreview.github.io/?https://github.com/rtitmuss/torn/blob/master/doc/release/torn_left-ibom.html)
and [right](https://htmlpreview.github.io/?https://github.com/rtitmuss/torn/blob/master/doc/release/torn_right-ibom.html)
PCBs to help find the right place for each component. It can also be useful to refer to the 
[left](./release/torn_left-schematic.pdf) and [right](./release/torn_right-schematic.pdf) schematics
if you need to understand the traces (wires) between the components.

### Left side

**Step 1**

**22 x 1n4148 Diodes (D1 - D22)**

THIS PART HAS A SPECIFIC ORIENTATION - the **black bar on the diode will point LEFT** and will line up with the square pad.

Bend the legs straight down as close to the diode as possible, insert, solder and clip the legs.



**Step 2**

**2 x 5.1k Blue resistors (R4, R5)**

Bend the legs straight down as close to the resistor as possible, insert, solder and clip the legs.



**Step 3**

**2 x 2.2k Blue resistors (R7, R8)**

Bend the legs straight down as close to the resistor as possible, insert, solder and clip the legs.



**Step 4**

**1 x 10k Blue resistor (R6)**

Bend the legs straight down as close to the resistor as possible, insert, solder and clip the legs.



**Step 5**

**2 x 75 Tan resistor (R2, R3)**

Bend the legs straight down as close to the resistor as possible, insert, solder and clip the legs.



**Step 6**

**1 x 1.5k Tan resistor (R1)**

Bend the legs straight down as close to the resistor as possible, insert, solder and clip the legs.



**Step 7**

**2 x 3.6V Zener Diode (D50, D51)**

THIS PART HAS A SPECIFIC ORIENTATION - the **black bar on the diode will point UP** and will line up with the square pad.

Bend the legs straight down as close to the diode as possible, insert, solder and clip the legs.



**Step 8**

**1 x 16MHz Crystal (Y1)**

Insert the crystal, solder and clip the legs.



**Step 9**

**2 x 22pF Capacitor (C1, C2)**

These capacitors are the smaller blue capacitors with straight legs.

Insert the capacitors, solder and clip the legs.



**Step 10**

**2 x 0.1uF Capacitor (C4, C5)**

These capacitors are the larger blue capacitors with wider legs.

Insert the capacitors, solder and clip the legs.



**Step 11**

**1 x USB4085 USB C port (USB1)**

Insert and tape the USB C port to the board. Flip board over. Solder only one of the large bottom legs. Check the port is flush before soldering the other three legs.  Remove the tape.

For the small pins you are going to use a different technique than the rest of the components. Apply no-clean flux paste across all pins. This step is possible without flux, but using it is highly recommended and will make the process much easier. Proceeding without flux for this step is not recommended. Apply a small amount of solder and drag your iron across the pins. Repeat until all holes are filled.



---
**NOTE**

When solering USB C port pins you might get bridges in two places (see image below), this is fine because all those pins are connected to ground.


---

**Step 12**

**1 x TRRS socket (J2)**

Tape the TRRS socket to the board. Flip the board over. Solder only one pin, and check to ensure it is flush before continuing. After checking solder the remaining pins. Remove the tape.



**Step 13**

**1 x 28 pin IC socket**

THIS PART HAS A SPECIFIC ORIENTATION - the **notch** on the IC sockets must be pointing **UP**.

Tape the IC socket to the board. Solder two opposite corners of the IC socket. Check the socket is flush before continuing. Solder the rest of the pins. Remove the tape.



**Step 14**

**2 x 6mm Push button (BOOT, RESET)**

Insert and solder BOOT and RESET switches.



**Step 15**

**1 x 4.7uF Capacitor (C3)**

THIS PART HAS A SPECIFIC ORIENTATION - the **longer leg** goes to the **square pad**, which is **UP**.

Insert the capacitor and solder. Fold down the capacitor as pictured after soldering. Clip the legs.



**Step 16**

**1 x 500ms Resettable fuse (F1)**

Insert the fuse, and solder. Fold down the fuse as pictured after soldering. Clip the legs.



**Step 17**

**1 x ATmega328P (U1)**

THIS PART HAS A SPECIFIC ORIENTATION - The **notch** on the ATmega328P must be pointing **UP**.

CHECK YOU HAVE THE RIGHT PART - it looks similar to U2, check the writing says **ATMEGA328P**.

Insert the ATmega328P. You may have to GENTLY bend the pins slightly inward for proper alignment with the socket.

### Right side

**Step 18**

**22 x 1n4148 Diodes (D23 - D44)**

THIS PART HAS A SPECIFIC ORIENTATION - the **black bar on the diode will point LEFT** and will line up with the square pad.

Bend the legs straight down as close to the diode as possible, insert, solder and clip the legs.



**Step 19**

**3 x 5.1k Tan resistor  (R50-52)**

Bend the legs straight down as close to the resistor as possible, insert, solder and clip the legs.



**Step 20**

**1 x 0.1uF Capacitor (C6)**

These capacitors are the larger blue capacitors with wider legs.

Insert the capacitors, solder and clip the legs.



**Step 21**

**1 x TRRS socket (J3)**

Tape the TRRS socket to the board. Flip the board over. Solder only one pin, and check to ensure it is flush before continuing. After checking solder the remaining pins. Remove the tape.



**Step 22**

**1 x 28 pin IC socket**

THIS PART HAS A SPECIFIC ORIENTATION - the **notch** on the IC sockets must be pointing **UP**.

Tape the IC socket to the board. Solder two opposite corners of the IC socket. Check the socket is flush before continuing. Solder the rest of the pins. Remove the tape.



**Step 23**

**3 x LED (L1, L2, L3)**

THIS PART HAS A SPECIFIC ORIENTATION - the **shorter leg** goes to the **square pad**, which is **LEFT**.

Insert the LEDs, solder and clip the legs.



**Step 24 (Optional)**

**1 x OLED display**

You can optionally add an OLED display.

THIS PART HAS A SPECIFIC ORIENTATION - the **pins** go on the **LEFT**.

Insert the Oled, solder and clip the legs.



**Step 25**

**1 x I/O Expander (U2)**

THIS PART HAS A SPECIFIC ORIENTATION - The **notch** on the MCP23017 must be pointing **UP**

CHECK YOU HAVE THE RIGHT PART - it looks similar to U2, check the writing says **MCP23017**.

Insert the I/O Expander. You may have to GENTLY bend the pins slightly inward for proper alignment with the socket.

### Let’s test

To test the keyboard connect the TRRS cable between the left and right sides, and then connect the USB C cable.
the cable must be a **TRRS cable** with **4 contacts** and NOT a TRS cable with 3 contacts.
You should always disconnect the USB C cable before inserting or removing the TRRS cable. 

The firmware is preinstalled if you’ve bought a kit, otherwise before continuing see the instructions to [flash the bootloader](bootloader.md) and [qmk](build.md#qmk).

It is a good idea to now test the board before adding the key switches. This is easiest with Via, so first download and install it from [https://caniusevia.com/](https://caniusevia.com/). Your new Torn keyboard should be automatically detected when you connect it to your PC.

Select the Key Tester tab, and enable Test Matrix. You can now test each key switch by shorting the contacts with tweezers or some wire. Make sure all switches work before continuing.

You can check the [troubleshooting guide](troubleshoot.md) if the keyboard is not working.



### Cases and Keyswitches

Congratulations the PCB assembly is complete. There are several different options for keyboard cases
and keyswiches. [Continue here](./build.md#torn-keyboard-cases)

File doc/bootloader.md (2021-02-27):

# Flashing the bootloader

If you bought the Torn Keyboard kit the ATmega328P has already been programmed, otherwise if you purchased your own components you need to follow this section of the guide.

This guide shows you how to use an [Arduino Uno](#Arduino-Uno-as-ISP) or an USBasp (on [Linux](#USBasp-as-ISP-on-Linux) / [Windows](#USBasp-as-ISP-on-Windows)) to program the keyboard. You can use other ISP programmers that are supported by avrdude.

You can check the [troubleshooting guide](troubleshoot.md#flashing-atmega328p) if you have problems programming the bootloader.

## Downloading the bootloader

Download the USBaspLoader source code from [https://github.com/rtitmuss/USBaspLoader/tree/torn](https://github.com/rtitmuss/USBaspLoader/tree/torn) by clicking on the green `Code` button and then on `Download ZIP`. Unzipp the files. 

You may need to modify the `PROGRAMMER` setting in `Makefile.inc` if you are using a different ISP programmer or OS. The next sections will skim over what to edit in case you are using an Arduino or a USBasp.

## Arduino Uno as ISP

First you need to program the Arduino Uno as an ISP, as described in Load the Sketch at [https://www.arduino.cc/en/Tutorial/ArduinoISP#toc5](https://www.arduino.cc/en/Tutorial/ArduinoISP#toc5).

### Wiring the programmer

You can use an Arduino Uno to program the AMegta328P with the ISP header on the right PCB. You need to connect the following pins:

Arduino Uno | Torn Keyboard
----------- | -------------
ICSP Pin 1 - MISO | ICP Pin 1 - COL4
ICSP Pin 2 - +Vcc | ICP Pin 2 - +5V
ICSP Pin 3 - SCK | ICP Pin 3 - COL3
ICSP Pin 4 - MOSI | ICP Pin 4 - COL5
ICSP Pin 5 - Reset | -
ICSP Pin 6 - Gnd | ICP Pin 6 - GND
Digital Pin 10 | ICP Pin 5 - Reset

The Arduino Uno board needs a 10µF electrolytic capacitor connected to RESET and GND with the positive (long leg) connected to RESET. The capacitor has to be placed after the programmer board has been loaded with the ISP sketch.



### Flashing

You may need to change the path to your Arduino in the `Makefile.inc`. Replace the path in line 41 `/dev/cu.usbmodem*` with your own.
```
41:     PROGRAMMER = -c avrisp -P /dev/cu.usbmodem* -b19200
```
Make sure to save your changes before continuing. 

Navigate to your unzipped `USBaspLoader-torn` folder and open a terminal window at that location. You can now flash the bootloader using:

```
    make
    make flash
    make fuse
```

Once the bootloader has been flashed to the board, disconnect the Arduino Uno.

## USBasp as ISP on Linux

> This section has been tested on Ubuntu Desktop version 20.10. If you don't have Ubuntu installed, you can run it from a [bootable USB stick](https://ubuntu.com/tutorials/create-a-usb-stick-on-windows#1-overview) without touching your current OS.

### Installing the required packages

1. Open a new Terminal window
2. run `sudo add-apt-repository universe`, press Enter when prompted.
3. run `sudo apt-get update`
3. run `sudo apt-get install avr-libc binutils-avr gcc-avr avrdude make`, press Y when prompted

### Testing your USBasp

Plug the USBasp into your computer. Connect the ribbon cable between your USBasp and the ISCP header on your keyboard. Make sure that the ribbon cable notch faces the right way.

Run `avrdude -c usbasp -p atmega328p` in your Terminal.

If everything is working you should get a message similar to this one: 

```
    avrdude: AVR device initialized and ready to accept instructions

    Reading | ################################################## | 100% 0.00s

    avrdude: Device signature = 0x1e950f (probably m328p)

    avrdude: safemode: Fuses OK (E:FC, H:D0, L:D7)

    avrdude done.  Thank you.    
```



### Flashing

Go into your previously downloaded and unzipped `USBaspLoader-torn` folder and edit `Makefile.inc`. Uncomment Line 40. Comment out Line 41. 

```
39:     # PROGRAMMER = -c pony-stk200
40:     PROGRAMMER = -c usbasp
41:     # PROGRAMMER = -c avrisp -P /dev/cu.usbmodem* -b19200
```
Make sure to save your changes before continuing. 

Navigate to your unzipped `USBaspLoader-torn` folder and open a terminal window at that location. You can now flash the bootloader using:

```
    make
    make flash
    make fuse
```

Once the bootloader has been flashed to the board, disconnect the USBasp.

## USBasp as ISP on Windows

> This section has been tested on Windows 10 version 20H2.

### Installing the required programs

If you don't have `QMK MSYS` already installed on your computer, go [HERE](https://msys.qmk.fm/) and install the latest version. Follow the `Get Started` section and come back here when you are done. You will also need `QMK MSYS` later if you want to create your own keymap.
1. Make sure `QMK MSYS` is installed.
2. Download [Zadig](https://zadig.akeo.ie/). You will need this program to install the correct driver for your USBasp on Windows.
3. Plug your USBasp into your computer.
4. Start Zadig and select `List all Devices` under `Options`.
5. You should now be able to select `USBasp`in the drop down menu.
6. Make sure `WinUSB`is selected as replacement driver.
7. Click on `Replace Driver` to start the progress and wait until it's done.
8. Close Zadiq. Unplug your USBasp.





### Testing your USBasp

Plug the USBasp into your computer. Connect the ribbon cable between your USBasp and the ISCP header on your keyboard. Make sure that the ribbon cable notch faces the right way.

Open `QMK MSYS` and run `avrdude -c usbasp -p atmega328p`.

If everything is working you should get a message similar to this one: 



### Flashing

Go into your previously downloaded and unzipped `USBaspLoader-torn` folder and edit `Makefile.inc`. Uncomment Line 40. Comment out Line 41. 

```
39:     # PROGRAMMER = -c pony-stk200
40:     PROGRAMMER = -c usbasp
41:     # PROGRAMMER = -c avrisp -P /dev/cu.usbmodem* -b19200
```
Make sure to save your changes before continuing. 

Navigate to your unzipped `USBaspLoader-torn` folder by typing `cd C:/Users/YOURUSERNAME/Downloads/USBaspLoader-torn` in `QMK MSYS`. Change the path according to your own and press Enter.



You can now flash the bootloader using:

```
    make
    make flash
    make fuse
```

Once the bootloader has been flashed to the board, disconnect the USBasp.

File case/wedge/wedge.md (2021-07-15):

# Torn Wedge Case

The Wedge Case has been designed for the Torn keyboard. It has been designed as a premium case option,
with an angled 3D printed case and a steel plate.

The case is manufactured for your individual requirements. You can choose a tenting angle between 7 
degrees to 30 degrees. The cases are printed on demand and can be made in a color of your choice, it
is even possible to try and match the color to your keycaps. Prices start from €150 plus shipping from Europe.
If your interested please contact me at richard.titmuss@gmail.com or on
[Discord](https://discordapp.com/users/745293992044003348/) for more information.



## What's included

The following parts are included in the Torn Wedge Case kit:



* 2 x base (3D printed)
* 2 x insert (3D printed)
* 2 x trim (3D printed)
* 2 x steel plate
* 2 x acrylic cover
* 8 x bumper feet
* 12 * M3 screws
* cali cat

You need a 2mm allen key (not included) for assembly.

## Finish

Care is taken during the manufacturing of the Wedge Case to produce the best possible finish, but
the Wedge Case is 3D printed which means that fine layer lines will be visible in the surface finish.
These close up photos are intended to show the imperfections!



A [cali cat](https://www.thingiverse.com/thing:1545913) is included with the kit in case you want to
experiment with a smoother finish. The case is printed using PETG plastic, you can read about
different options for [getting the perfect finish](https://all3dp.com/2/petg-smoothing/). 



Threaded brass inserts are used for a secure and wear resistant assembly. 



The case has room for the TRRS and USB C connectors to attach to the PCB.



## Build Guide

Before assembling the Wedge Case you need to have assembled the [Torn PCBs](../../doc/pcb.md). Complete
the following steps for the left and right sides of your keyboard.

### Step 1

The assembled Wedge weights about 500g. If you want to add some weight for a quality feel and to
make sure it won't more around your desk you can add some extra weight at the bottom of the case.



A cost effective was to add weight is to use adhesive balance weights for car wheels. Below eight 60g
strips are used to add approx 500g additional weight. These are easy to buy from Amazon, for example
[US](https://www.amazon.com/Pit-Posse-Balancing-Weights-Adhesive/dp/B00OQWS98S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),
[UK](https://www.amazon.co.uk/FIERCE-CYCLE-Balance-Weights-Motorcycle/dp/B07QQ539GV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),
[SE](https://www.amazon.se/gp/product/B01GHKG18G/ref=ppx_yo_dt_b_asin_image_o00_s00?ie=UTF8&psc=1).



## Step 2

Press the insert firmly into the base. This is designed to be a tight fit, and it is important that
the insert is correctly seated.

Be careful if you need to remove the insert; you can use a small screwdriver to pry the insert up
by the connector gap.



## Step 3

Remove the steel plate from the protective wrapper.



## Step 4

Insert some MX switches in the steel plate and attach the completed PCB. Be careful not to bend the
switch pins.



## Step 5

Add the rest of the MX switch. Be careful not to bend the switch pins.

If you are not using Kailh sockets, you need to solder the switches to the PCB. You might want to
test all the switches are working before proceeding.



## Step 6

Put the steel plate and PCB assembly on the Wedge.



## Step 7

Put the trim over the steel plate. Remove the protective sheet on the acrylic cover and place it
over the trim. Use three M3 screws to secure the acrylic cover.



## Step 8

Turn the case over and using three M3 screws to secure the trim. Add four bumper feet.



## Step 9

Add the keycaps and enjoy your new keyboard!



The completed keyboard weights about 500g for each half.



When using additional weights it is easy to increase this to 900g+ for each half.



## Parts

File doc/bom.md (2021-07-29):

# Parts list

The easy option is to wait until later this year when a Torn keyboard kit will be available at [splitkb.com](https://blog.splitkb.com/blog/january-2021).

You can also source and buy the following parts.

Torn is licensed under licensed under the [Creative Commons Attribution-NonCommercial 4.0 International License](https://creativecommons.org/licenses/by-nc/4.0).
This PCB design may be freely reproduced, modified, and manufactured for personal use only. It is not permitted to sell spare PCBs without permission.

### PCBs

There are several PCB manufactures that can produce small production runs, for example [jlcpcb](https://jlcpcb.com/), [PCBway](https://www.pcbway.com/) and [Elecrow](https://www.elecrow.com/pcb-manufacturing.html).
You will need upload the gerber files for the left and right PCBs. The latest version is published on [github](https://github.com/rtitmuss/torn/releases/latest) or you can generate your own gerbers using [KiCad](https://kicad.org/).

At the same time you can also manufacture the optional PCB plate and base, also available on [github](https://github.com/rtitmuss/torn/releases/latest).

### Components

You will also need to buy the components listed in the [bill of materials](https://octopart.com/bom-tool/5oG983n7). Most of the parts are easily available, with the exception of the USB C connector which is currently only stocked at Digi-Key in low volumes.

If you want the optional OLED display look for a 128X32 OLED Screen. This is the same OLED display used on the Corne and Lily58 keyboards, and available at many mechanical keyboard stores or [Aliexpress](https://www.aliexpress.com/i/32798439084.html).

Also optional are the Kailh MX Hotswap sockets, search for part number CPG151101S11.

### Cover

You will need to get an arcylic cover cut.

### Screws and standoffs

If you use PCB plate and base you will need M2 screws and standoffs. For example for the MX plate case:
- [M2 screws](https://www.aliexpress.com/item/32948706855.html) (3mm 26 pcs, 5mm 6 pcs)
- [M2 standoffs](https://www.aliexpress.com/item/32968830934.html) (3mm 10 pcs, 8mm 6 pcs)
- [M2 standoffs](https://www.aliexpress.com/item/32970235195.html) (3mm+3mm 16 pcs)

The Kailh Choc plate case requires:
- [M2 screws](https://www.aliexpress.com/item/32948706855.html) (3mm 16 pcs, 5mm 6 pcs)
- [M2 standoffs](https://www.aliexpress.com/item/32968830934.html) (5mm or 8mm 6 pcs)

You also want 8 rubber dome feet.

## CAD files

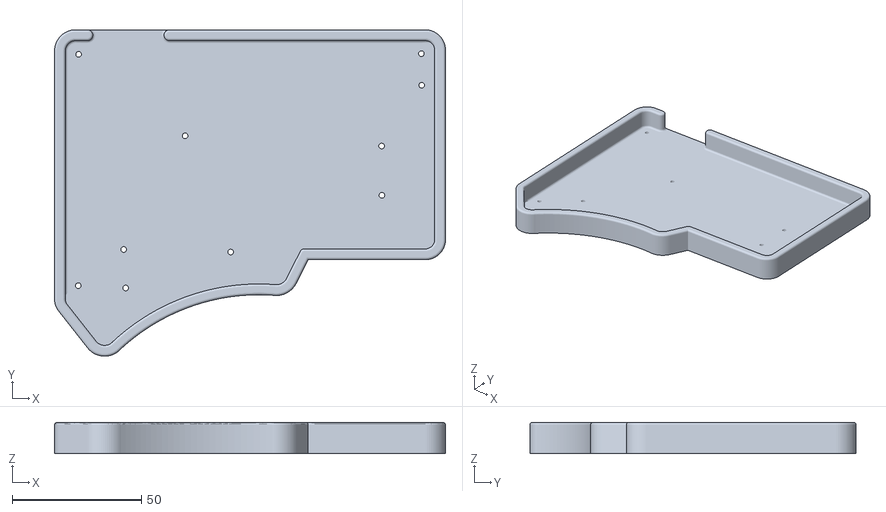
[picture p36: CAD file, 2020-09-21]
case/3D Printed Case/torn-case-v2.stl
151.1 x 126.2 x 12.0

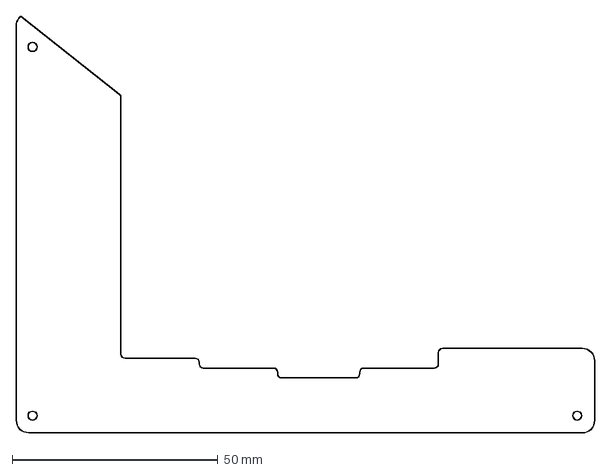
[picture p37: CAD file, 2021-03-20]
case/cover.dxf
140.7 x 101.3 mm

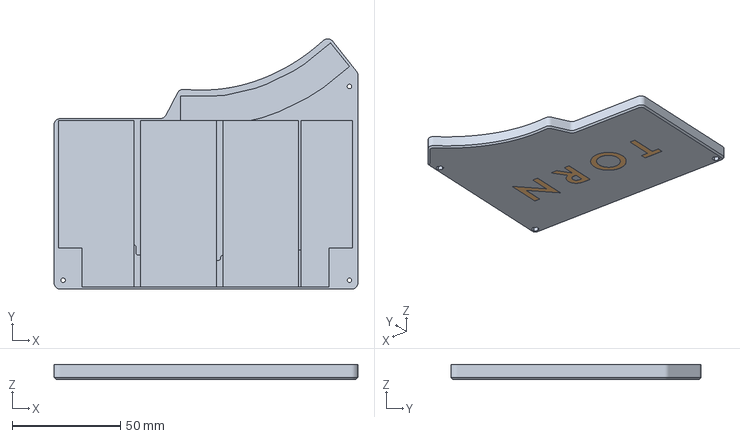
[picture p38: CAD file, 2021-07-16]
case/HiPro Case/stl/Right base.3mf
140.7 x 115.9 x 7.00 mm
Right base.stl
Torn Right.stl

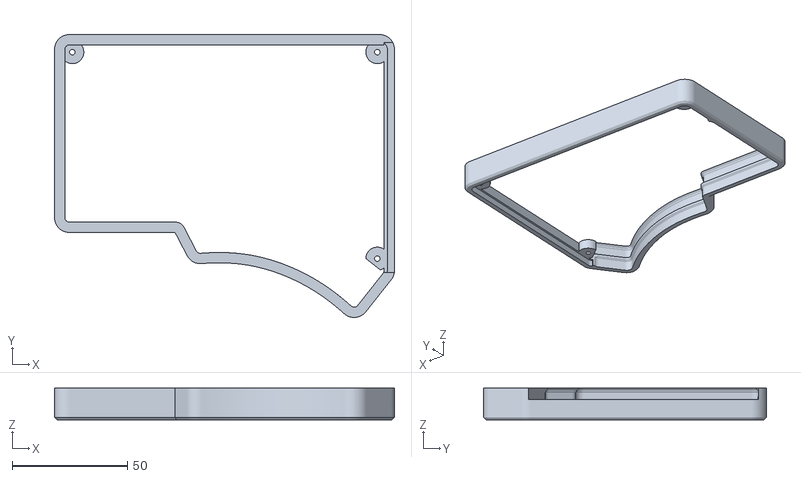
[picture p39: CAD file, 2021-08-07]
case/Travel Case/stl/Right basic.stl
147.7 x 122.9 x 13.7

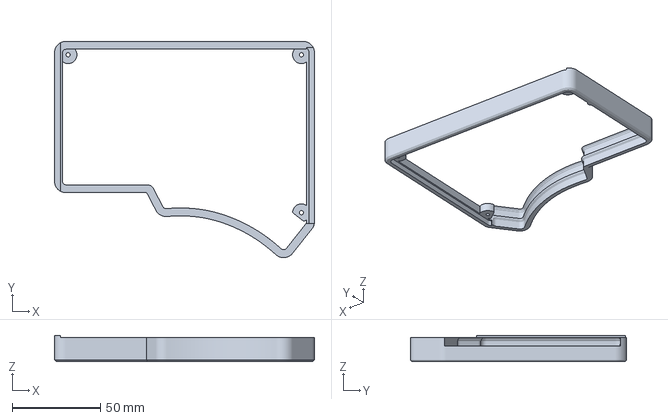
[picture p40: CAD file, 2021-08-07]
case/Travel Case/stl/Right macbook.3mf
147.7 x 122.9 x 14.9 mm

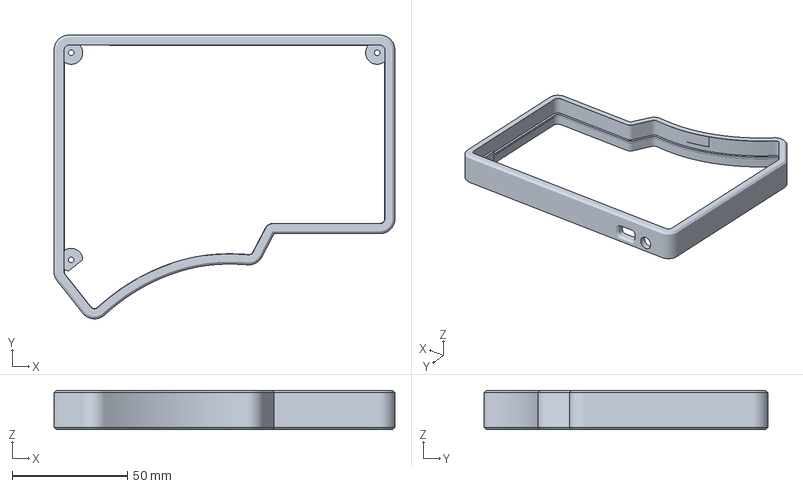
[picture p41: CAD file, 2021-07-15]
case/HiPro Case/stl/Right Choc top.3mf
147.7 x 122.9 x 17.1 mm

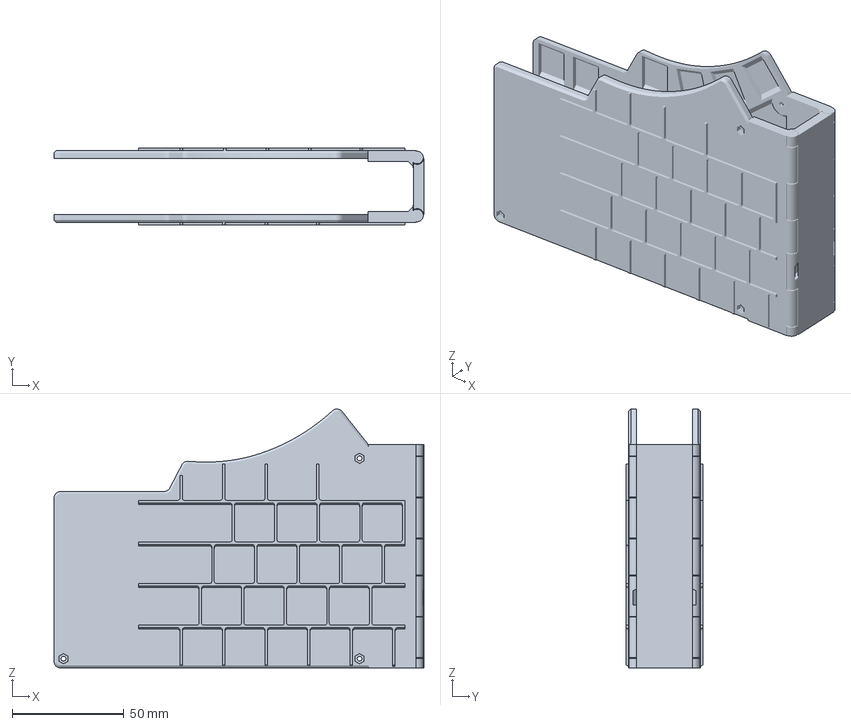
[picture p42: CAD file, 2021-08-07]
case/Travel Case/stl/Base macbook.3mf
165.6 x 34.6 x 115.9 mm

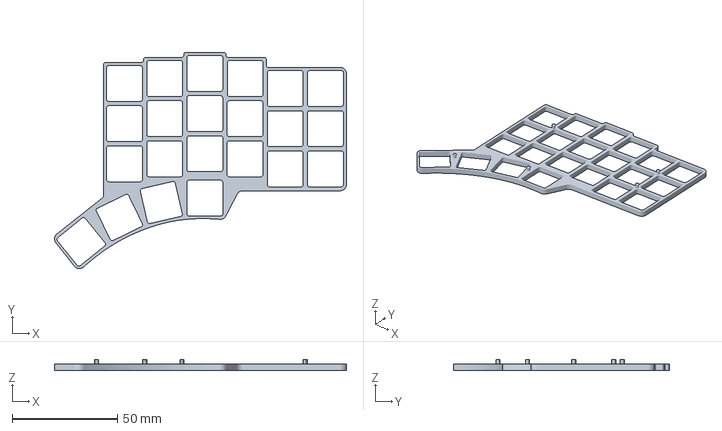
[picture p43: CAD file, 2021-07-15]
case/HiPro Case/stl/Right MX Spacer.3mf
138.4 x 102.5 x 5.00 mm

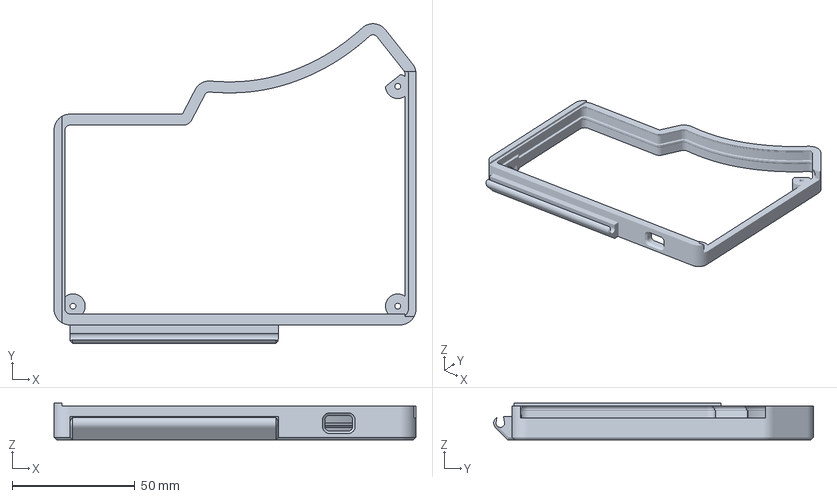
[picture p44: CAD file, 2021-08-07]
case/Travel Case/stl/Left macbook.3mf
147.7 x 130.4 x 14.9 mm

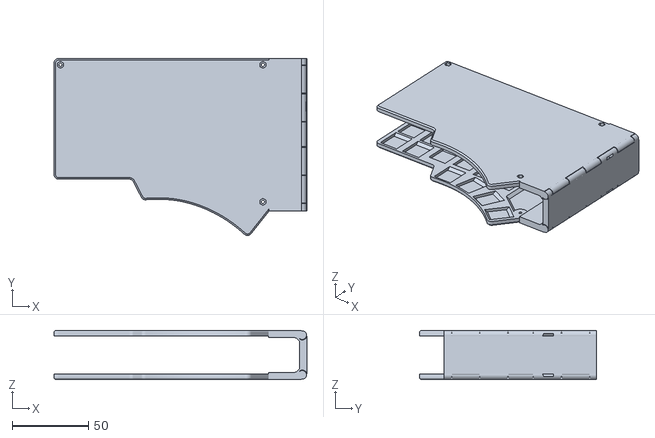
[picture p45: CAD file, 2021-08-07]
case/Travel Case/stl/Base basic.stl
165.6 x 115.9 x 32.2

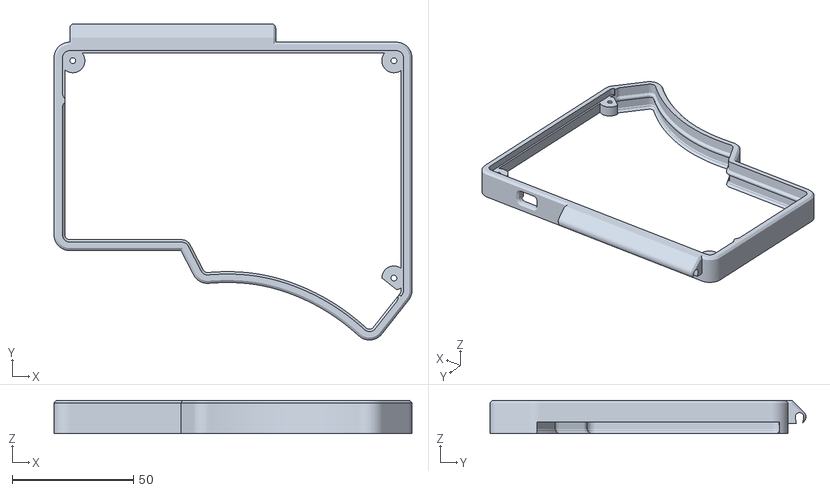
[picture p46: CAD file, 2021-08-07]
case/Travel Case/stl/Left basic.stl
147.7 x 130.4 x 13.7

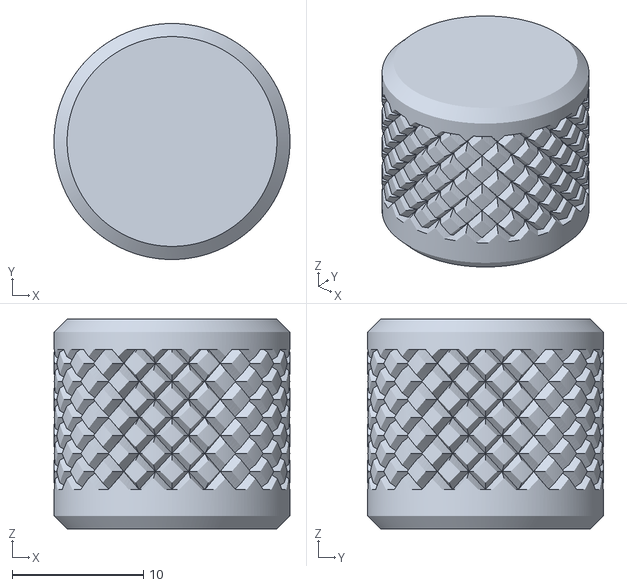
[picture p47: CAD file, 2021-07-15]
case/HiPro Case/stl/EC11 Knob.stl
18.0 x 18.0 x 16.0

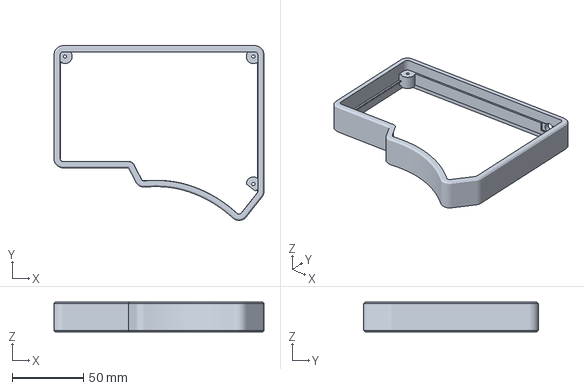
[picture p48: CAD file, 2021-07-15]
case/HiPro Case/stl/Right MX top.3mf
147.7 x 122.9 x 21.1 mm

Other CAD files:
case/HiPro Case/stl/Left base.3mf
case/HiPro Case/stl/Left Choc top.3mf
case/HiPro Case/stl/Left MX top.3mf
case/HiPro Case/stl/Left MX Spacer.3mf
case/HiPro Case/stl/Left Choc top.stl
case/HiPro Case/stl/Left MX Spacer.stl
case/HiPro Case/stl/Left MX top.stl
case/HiPro Case/stl/Left base.stl
case/HiPro Case/stl/Right Choc top.stl
case/HiPro Case/stl/Right MX Spacer.stl
case/HiPro Case/stl/Right MX top.stl
case/HiPro Case/stl/Right base.stl
case/Travel Case/stl/Base macbook.stl
case/Travel Case/stl/Left macbook.stl
case/Travel Case/stl/Right macbook.stl

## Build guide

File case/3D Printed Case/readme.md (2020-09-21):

Uploaded this case designed by u/bomtarnes / keyboard-magpie using the pcb files for v2.1 torn pcb.

torn

Case design falls under same licensing as the main torn project.

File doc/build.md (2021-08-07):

# Torn Keyboard Build

Welcome to the Torn keyboard build instructions.

## You Need

You need the following components (not included in the Torn Keyboard kit).

Cherry MX compatible build:

*   USB C cable
*   TRRS cable
*   42-44 x MX Cherry MX compatible switches \
42-44 x Kailh PCB Socket CPG151101S11 **(optional)**
*   Keycaps for MX switches
*   2 x EC11 Encoders and knobs **(optional)**

Kailh low profile (choc) build:

*   USB C cable
*   TRRS cable
*   42-44 x Kailh low profile switch PG1350
*   Keycaps for Kailh low profile switches
*   2 x EC11 Encoders and knobs **(optional)**

Note: the cable must be a **TRRS cable** with 4 contacts and NOT a TRS cable with 3 contacts.

## Torn PCB Assembly

Follow the [PCB assembly instructions](pcb.md) to solder the components on the left and right sides 
of the keyboard. Test the keyboard is working before installing it in a case.

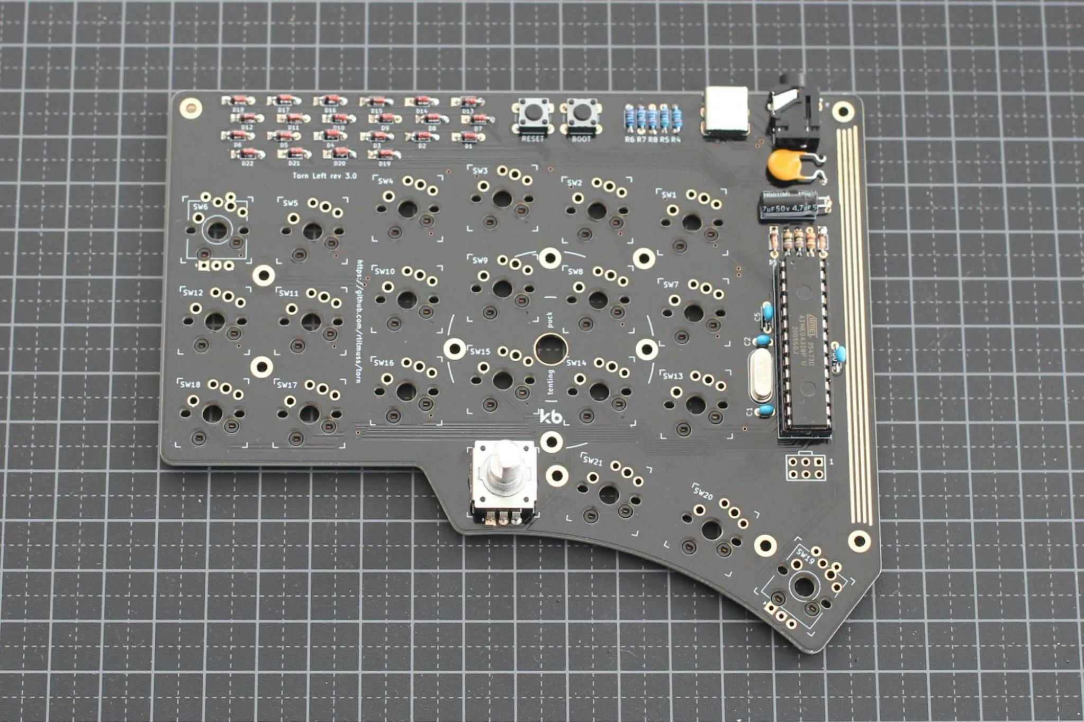
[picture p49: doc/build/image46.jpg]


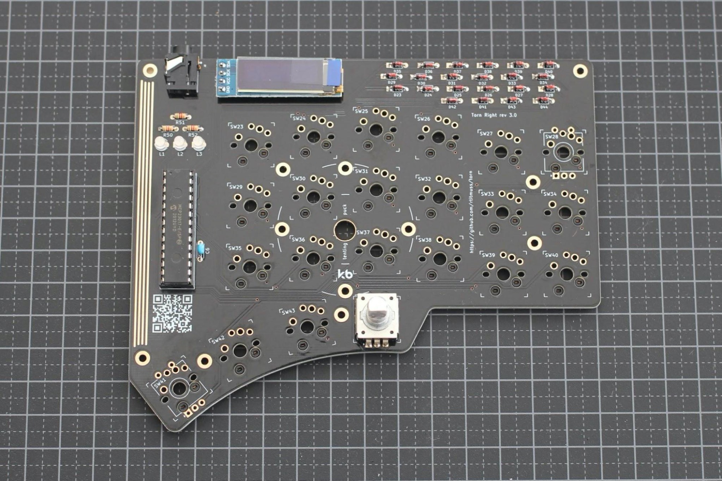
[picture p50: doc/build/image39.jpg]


## Torn Keyboard Cases

The completed PCBs can be installed in a keyboard case. There are several options available, or you could
design your own!

### Torn Wedge Case

The Wedge Case has been designed for the Torn keyboard. It has been designed as a premium case option,
for MX Switches, weighing approx 500g with an angled 3D printed case and a steel plate. Follow the
[Wedge Case instructions](../case/wedge/wedge.md) for more information or to assemble the wedge case.



### Weighted HiPro Case

This [3d printed Weighted HiPro Case](../case/HiPro%20Case/readme.md) is designed for MX or Kailh Choc switches. This case is designed
with a snap fit assembly, and to include 200g weight in each half.

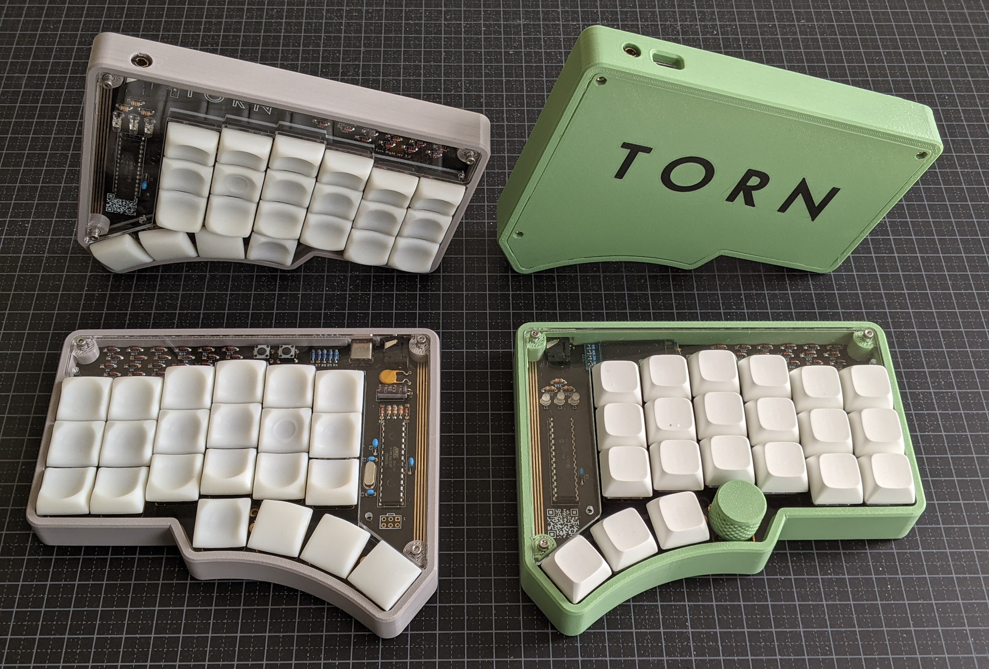
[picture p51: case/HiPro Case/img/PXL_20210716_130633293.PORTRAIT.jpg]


### Travel Case

You can 3d print a folding [travel case](../case/Travel%20Case/readme.md) designed for Kailh Choc
switches and a 15 inch Macbook Pro.

torn

### PCB Plate with MX Switches

You can use a PCB Plate case with MX Swtiches, see the [PCB Plate instructions](./build_mx.md)
for more information.

torn

### PCB case with Kailh Choc Switches

If you prefer a low profile keyboard you can use Kailh Choc Switches, see the [ Choc Switches instructions](build_choc.md)
for more information.

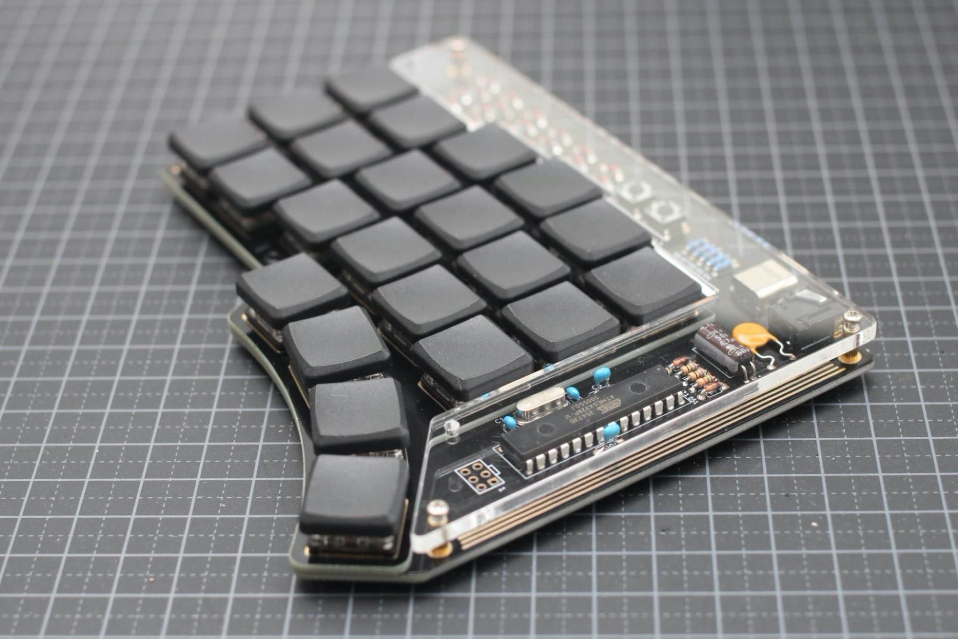
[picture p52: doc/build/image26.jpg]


### 3d printed case

You can [3d print](../case/3D%20Printed%20Case/readme.md) a case that can be used with either MX Switches or Kailh Choc Switches.

torn

## Configuring Torn Keyboard

If you bought the Torn Keyboard kit the ATmega328P has already been programmed, and you can use VIA or flash QMK as decribed below. Otherwise if you purchased your own components you will need to first [flash the bootloader](bootloader.md).

### VIA

You can use VIA to configure the Torn Keyboard. Download and install Via from [https://caniusevia.com/](https://caniusevia.com/). VIA will allow you to dynamically remap the keys when you plug the keyboard in.

To erase the configuration and return to the default settings, press the top left button on the keyboard when plugging in the USB C connector.

If you want to change the rotary encoder settings, or customize the OLED display you must download the QMK firmware and follow the instructions for Programming QMK.

### QMK

You can fully customize your Torn Keyboard by updating QMK.

Download the QMK source code from [https://github.com/qmk/qmk_firmware](https://github.com/qmk/qmk_firmware). You can then edit the source code, for example [creating our own keymap](https://docs.qmk.fm/#/custom_quantum_functions).

Enter bootloader mode by:

1. Plug in the TRRS cable to connect the left and right sides for the keyboard
2. Plug in USB C cable between the keyboard and your PC
3. Push and hold RESET SW
4. Push and hold BOOT SW
5. Release RESET SW
6. Release BOOT SW

You can then program QMK using:

```
make torn:via:flash
```

For additional help flashing QMK please see [https://docs.qmk.fm/#/newbs_flashing](https://docs.qmk.fm/#/newbs_flashing).

## Enjoy!

Congratulations on completing your Torn keyboard! It was fun designing and sharing this keyboard and
I enjoy seeing pictures of the finished build. So take a photo (tips for your
[phone](https://switchandclick.com/how-to-take-better-photos-of-your-keyboard-among-other-things/)
or [dslr](https://golem.hu/article/keyboard-photography/)) and share in
[Discord](https://discord.gg/mamAqNccju) or on [Reddit](https://www.reddit.com/r/ErgoMechKeyboards/).

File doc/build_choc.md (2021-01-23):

# Kailh Choc Switches

The following instructions are for Choc switches. You need to do all steps on both the left and right boards. You can also use the optional EC11 encoders and OLED display with Choc switches, but I choose to leave them both off for this build.

When using Choc switches it looks better if you lower the acrylic cover, to do this don’t use the IC sockets (steps 13 and 22 in the main instructions) and solder the ATMega328P and MCP23017 directly to the PCB.



The mechanical assembly will follow this diagram:



**Step 1**

Place the pcb plate on the main pcb, and insert a few Choc switches. Make sure everything fits correctly. Then add the remaining switches.

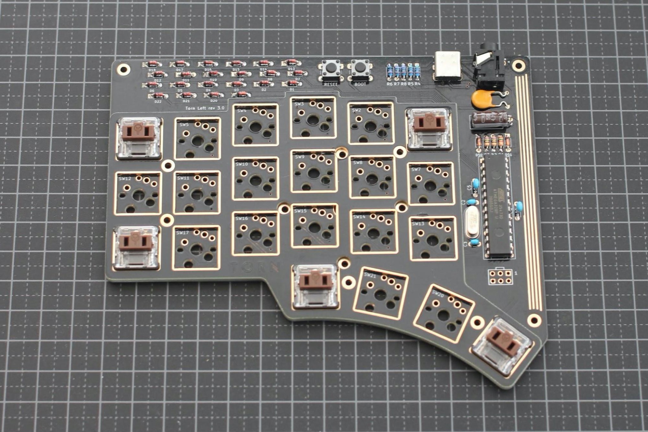
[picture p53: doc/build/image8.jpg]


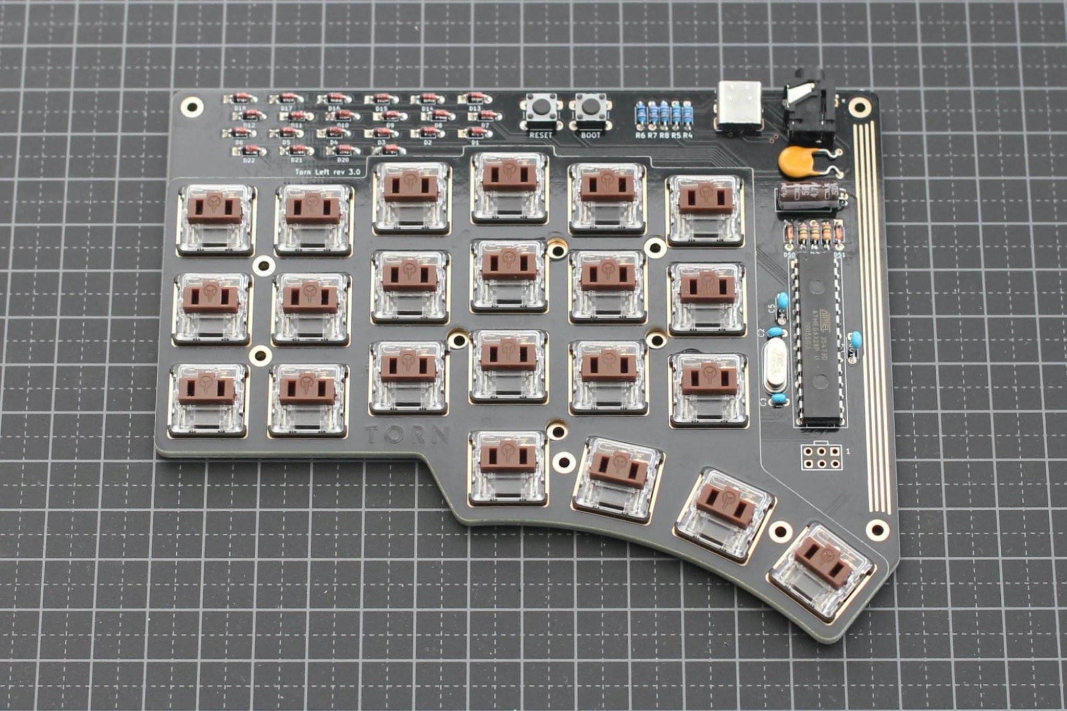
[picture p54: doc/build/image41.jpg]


**Step 2**

Check that the switches are all inserted correctly, then solder the switches.

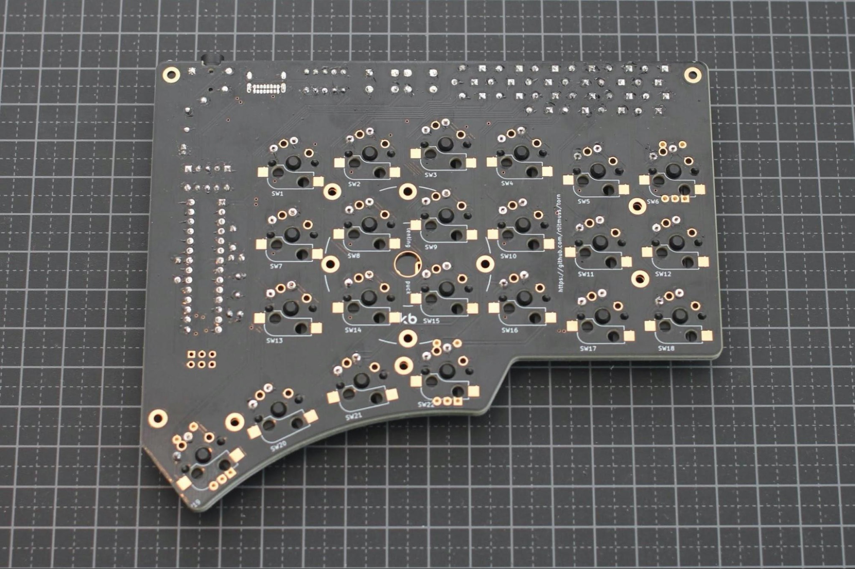
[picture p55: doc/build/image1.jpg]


**Step 3**

Attach the 5mm standoffs or the acrylic cover using 3mm screws. If you used IC sockets, use 8mm standoffs.

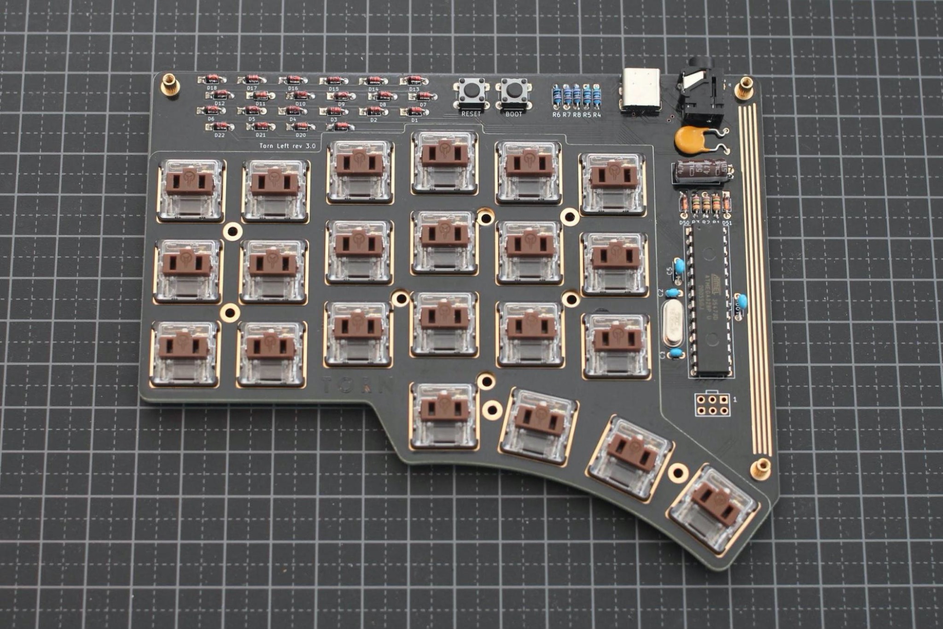
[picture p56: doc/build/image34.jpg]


**Step 4**

Attach the acrylic covers using 5mm screws, and fit the keycaps.



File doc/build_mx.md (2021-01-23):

# MX Switches with Kailh sockets

The following instructions are for MX Switches with Kailh sockets. You need to do all steps on both the left and right boards.

The mechanical assembly will follow this diagram:



**Step 1**

**42-44 x Kailh Sockets**

Solder the Kailh Sockets on the reverse of the board. Do not add a socket where you will be using the optional EC11 encoders (for example sw22 in the diagram below).

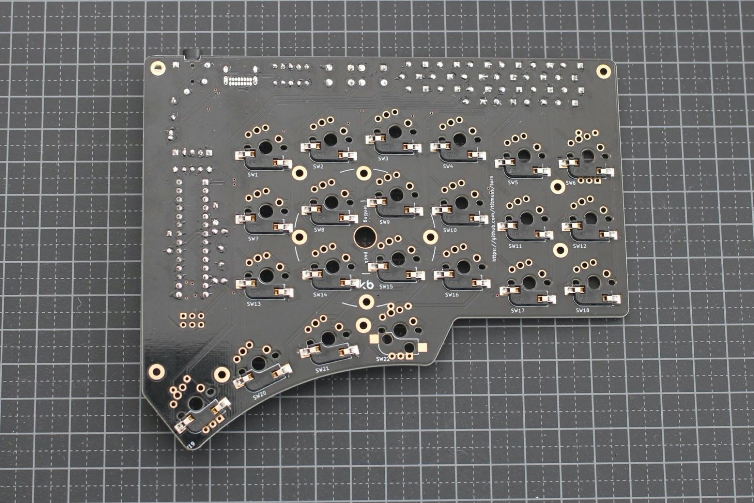
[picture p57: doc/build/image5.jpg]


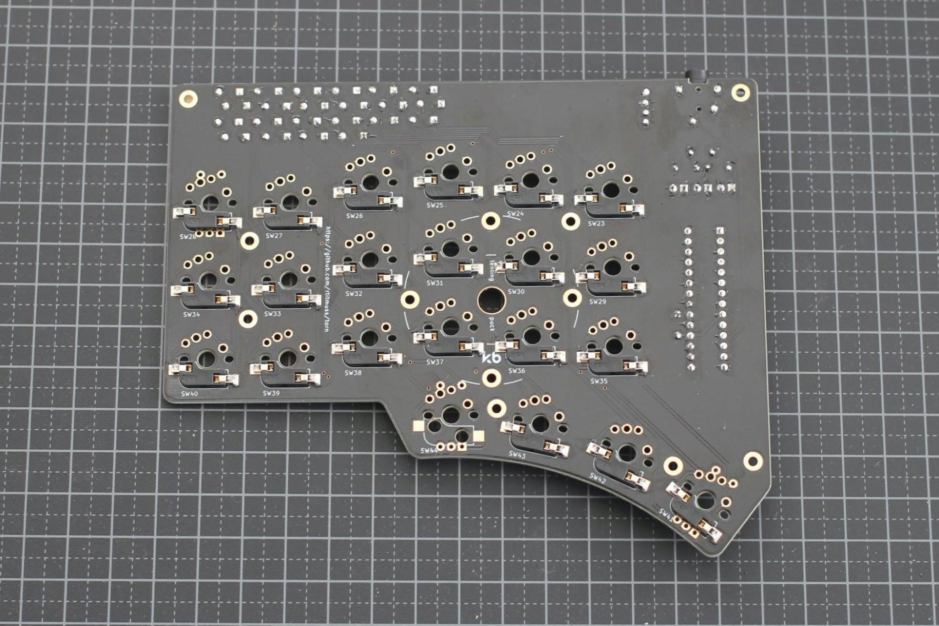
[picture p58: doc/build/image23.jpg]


**Step 2**

**2 x EC11 encoder (optional)**

You can optionally use EC11 encoders, in one of three positions marked on the board with the square. To fit the encoder you must first clip the two larger mounting pins on the sides of the encoder (adding the fixing holes on the pcb would have interfered with the key switch positions).

Solder one of the encoder legs and then check that the encoder is mounted squarely. Solder the remaining encoder legs to the pcb.





Apply a small piece of electrical tape to the encoder, this will prevent the encoder legs shorting on the pcb plate.

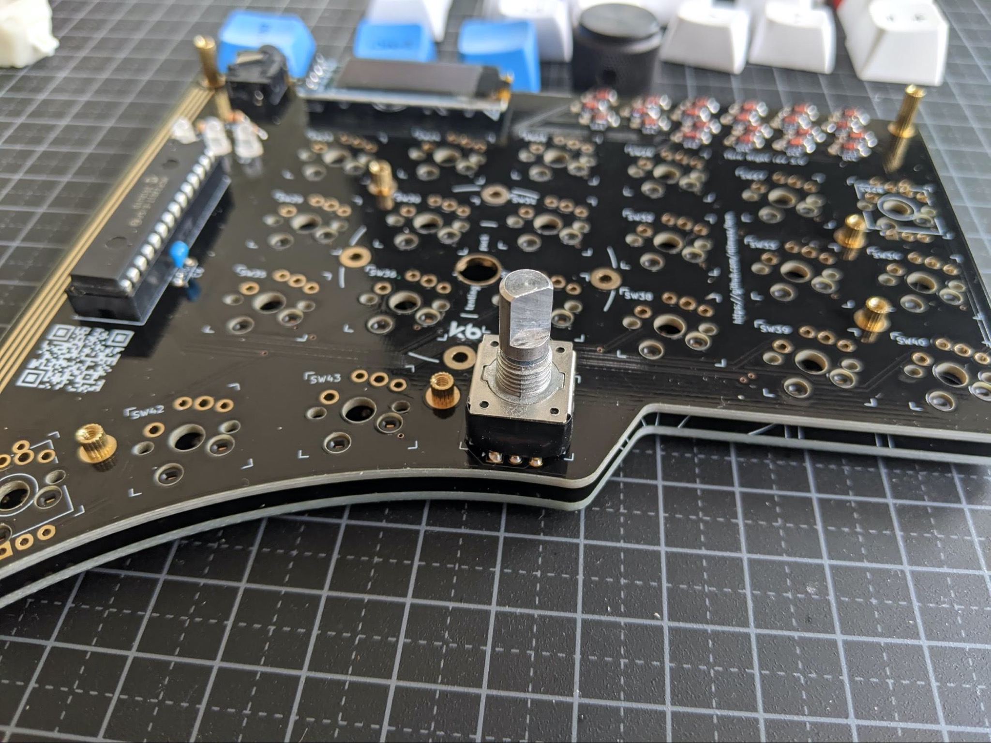
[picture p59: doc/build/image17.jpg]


**Step 3**

The metal plating on some of the holes in the pcb plate is not perfect, so check the fit of the switches before the next step. I have found that occasionally Gazzew Boba U4 switches would stick in some of the thumb positions, and this might happen with other types of switches too. If you find a switch is sticking, use a small metal file to smooth the inside edges of the plate.

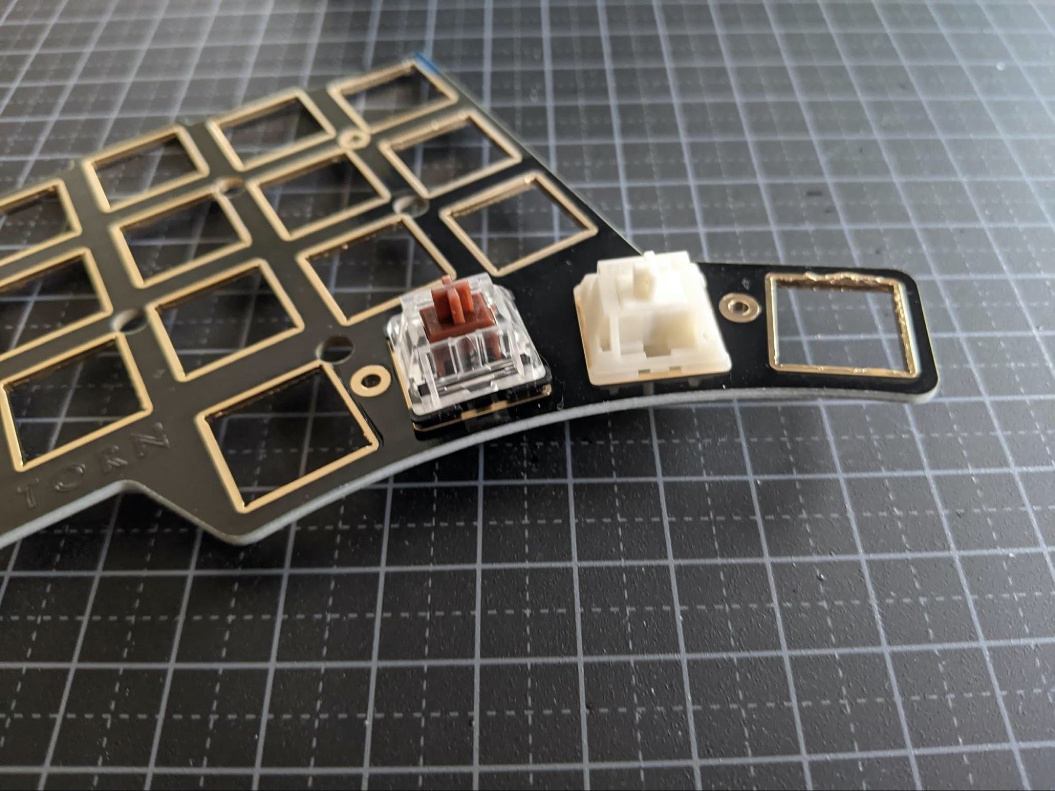
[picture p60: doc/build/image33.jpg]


**Step 4**

Attach the 3+3mm standoffs with 3mm screws in the mounting holes of the pcb plate, and then put the plate on the main pcb.

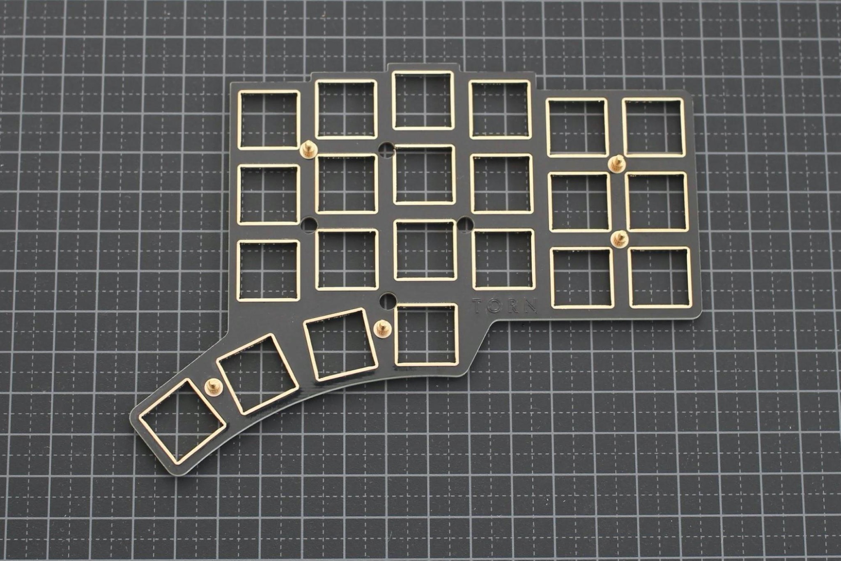
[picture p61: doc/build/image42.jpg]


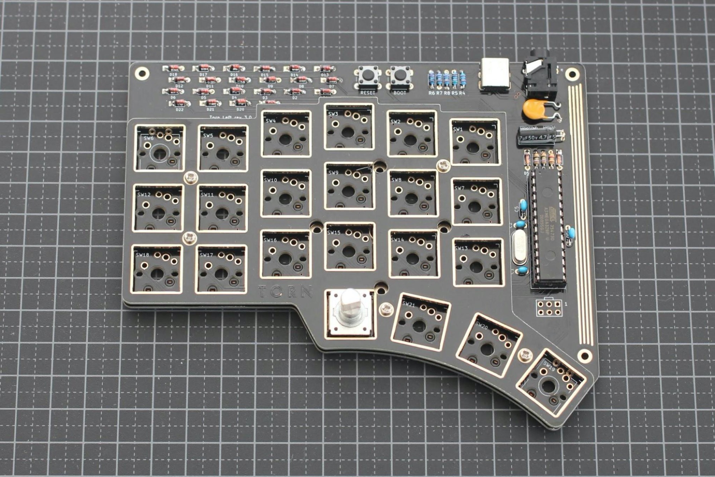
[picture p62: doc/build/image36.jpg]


**Step 5**

Insert the switches through the pcb plate into the Kailh sockets. Keep the main pcb on a flat surface while installing the switches so that the sockets are supported.

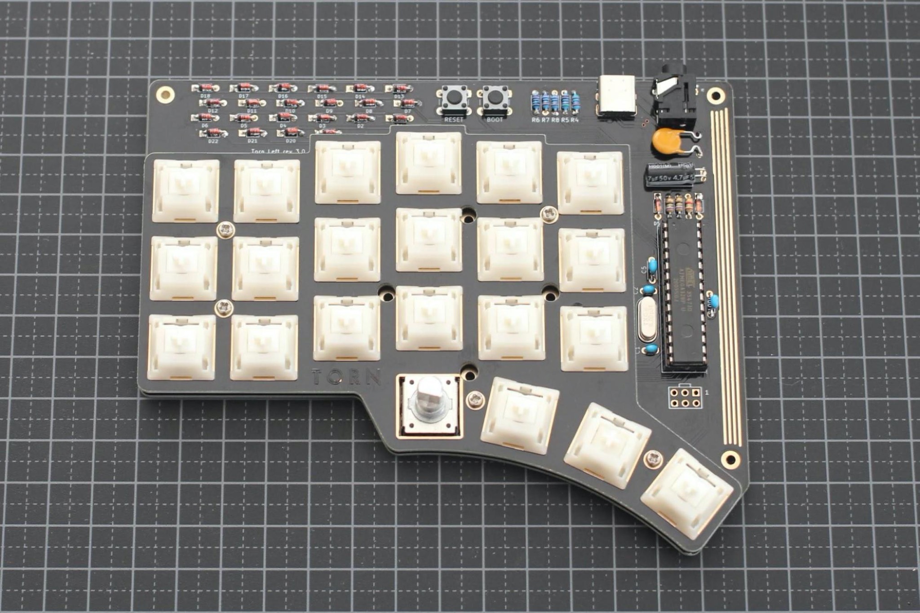
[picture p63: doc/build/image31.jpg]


**Step 6**

Secure the plate using 3mm standoffs.

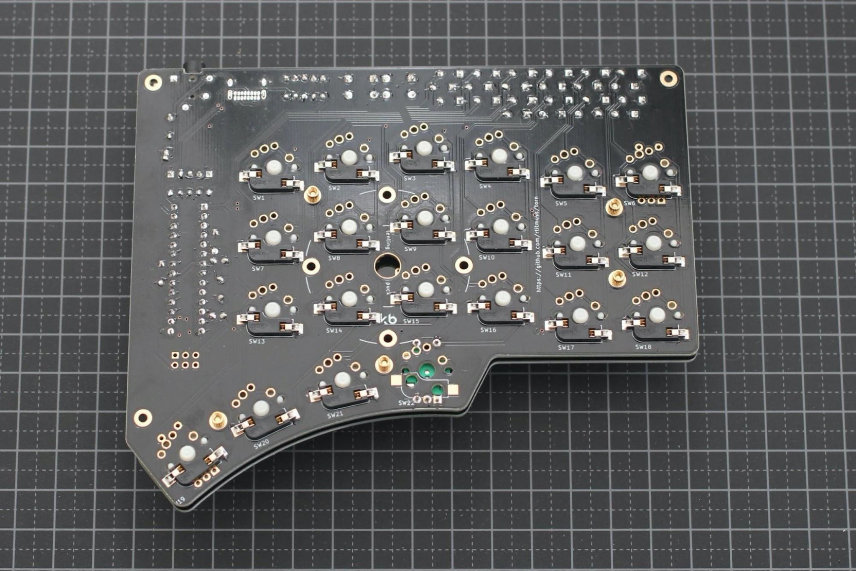
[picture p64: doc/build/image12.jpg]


**Step 7**

Attach the 8mm and 3+3mm standoffs for the acrylic cover.

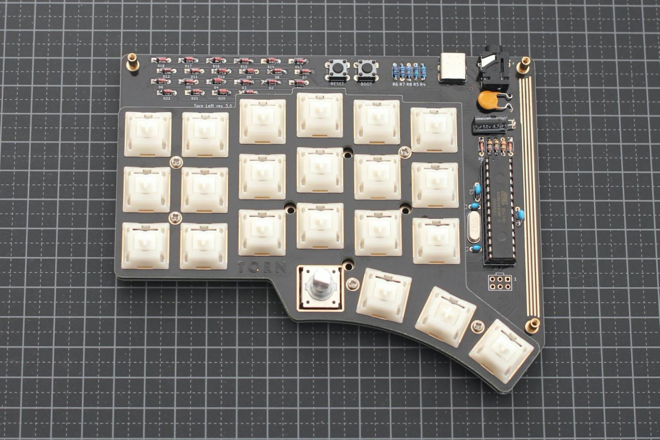
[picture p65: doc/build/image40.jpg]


**Step 8**

Use 3mm screws to attach the base. Attach the feet where shown.

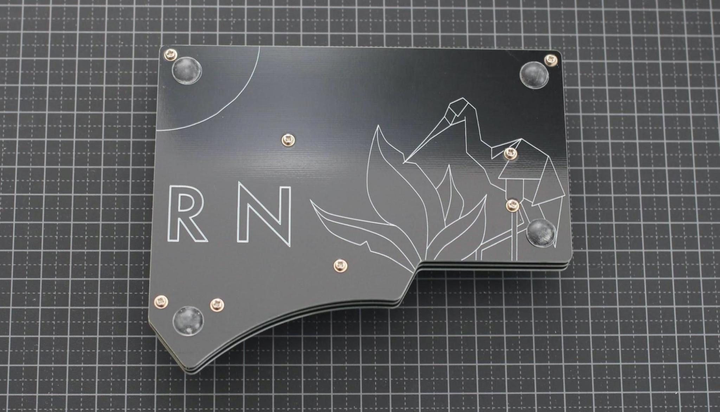
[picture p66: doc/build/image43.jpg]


**Step 9**

Attach the acrylic covers using 5mm screws.

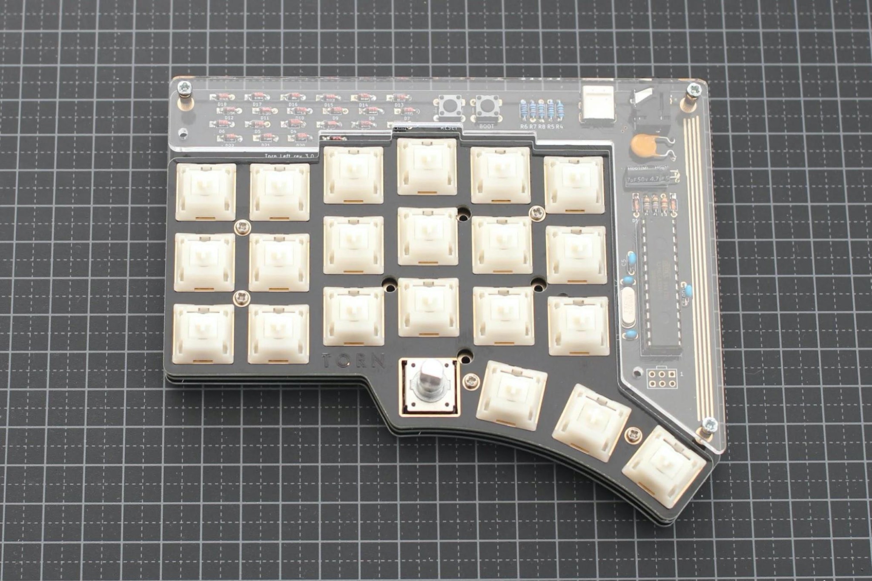
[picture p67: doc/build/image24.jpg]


**Step 10**

Finally add the keycaps and knobs. You're finished!

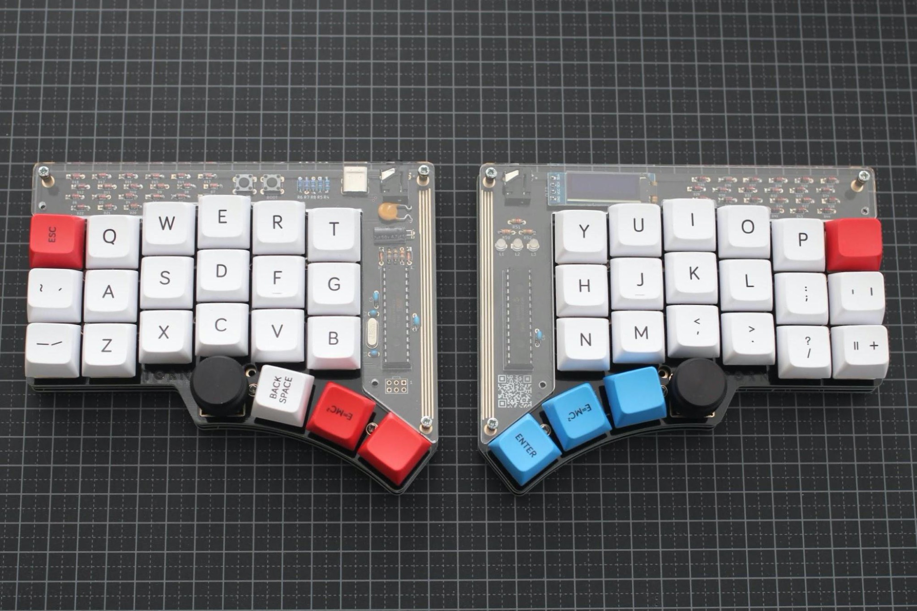
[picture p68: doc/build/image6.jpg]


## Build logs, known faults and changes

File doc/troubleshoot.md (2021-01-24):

# Troubleshooting

If your Torn keyboard does not work you can look for answers here.
You can also ask questions and get help on the [Torn Discord channel](https://discord.gg/mamAqNccju).

## Primary (left) side

The primary side of the keyboard is on the left. This side include the ATmega328P CPU. The pinout is shown below: 

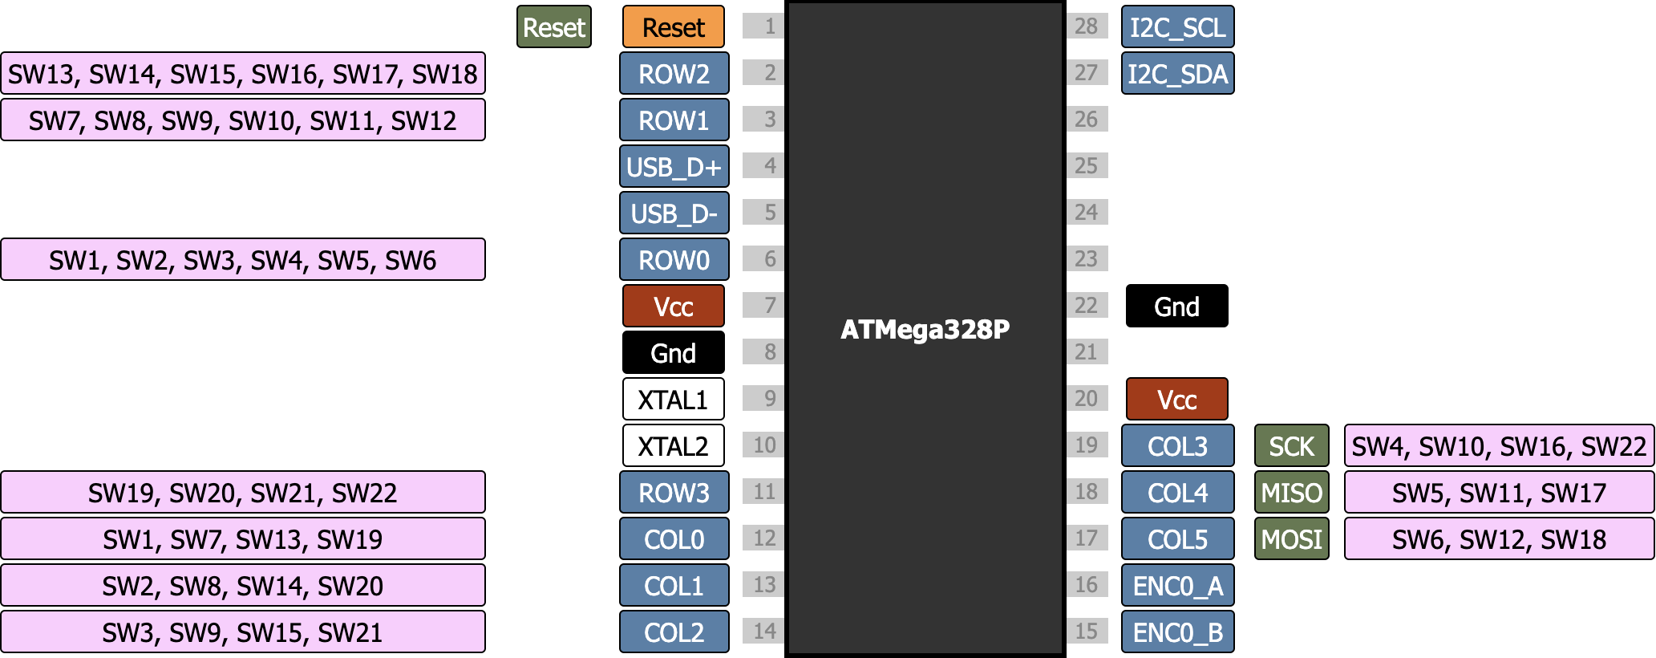
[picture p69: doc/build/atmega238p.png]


You can use the primary side of the keyboard on it's own, so unplug the TRRS cable to test.

If the keyboard does not work you should visually check the soldering and look for any shorts between the pins.
Pay special attention to the USB C connector and the 4.7uF Capacitor (C3).

Make sure the you have inserted the ATmega328P on the right side, and that the notch is pointing up.

#### Flashing ATmega328P

If you have trouble flashing the ATmega328P you can check that that programmer is connected correctly.
The ISP header has the following pinout:



You can use a multimeter to check the continuity between the ISP header and the ATmega328P. If necessary re-solder the connection.

- pin 1 (MISO) on the isp header should connect to pin 18 on ATmega328P
- pin 2 (Vcc) on the isp header should connect to pins 20 and 7 on ATmega328P
- pin 3 (SCK) on the isp header should connect to pin 19 on ATmega328P
- pin 4 (MOSI) on the isp header should connect to pin 17 on ATmega328P
- pin 5 (Reset) on the isp header should connect to pin 1 on ATmega328P
- pin 6 (Gnd) on the isp header should connect to pins 22 and 8 on ATmega328P

When the programmer is connected check you have 5v between pin 20 and pin 22 on the ATmega328P.

If you are still having problems you can also carefully remove the ATmega328P and try to [program it directly](https://www.hackster.io/techmirtz/arduino-without-external-clock-crystal-on-atmega328-d4fcc4). 
If this fails you may need to replace the ATmega328P.

## Secondary (right) side

The secondary side of the keyboard is on the right. This side includes the MCP23017 I/O expander. The pinout is shown below:

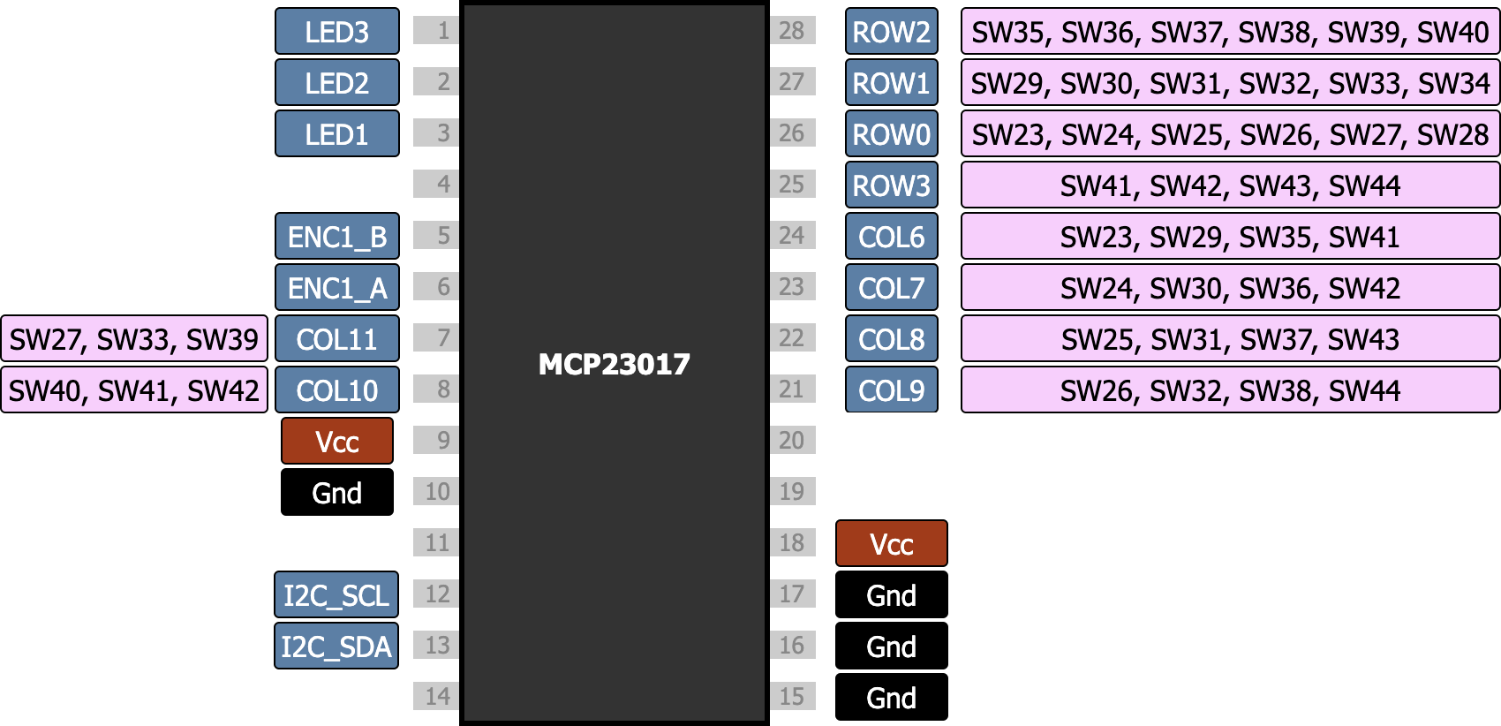
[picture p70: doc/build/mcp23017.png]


You have to connect the two halfs of the keyboard together with a TRRS cable.
Make sure you unplug the USB C before disconnecting the TRRS cable - otherwise the connector might short and destroy the chips.

#### I2C

The primary and secondary side communicate over I2C, a serial bus protocol. I2C is used for both the I/O expander and the OLED display.
If nothing works on the secondary side there is a prbolem with the I2C bus.

Check you are using a TRRS cable with four contacts on the plug. The cable supplies Vcc, Gnd, I2C_SCL and I2C_SDA. Note the keyboard will _not_ work with a TRS cable that has only three contacts.

You should also check that the I2C pull-up resistors R7 and R8 are soldered correctly.

With the TRRS cable connected you can check for connectivity between the two halves. If necessary re-solder the connection.

- pin 7 (Vcc) on ATmega328P should connect to pin 9 and 18 on MCP23017
- pin 8 (Gnd) on ATmega328P should connect to pin 10, 15, 16 and 17 on MCP23017
- pin 28 (I2C_SCL) on ATmega328P should connect to pin 12 on MCP23017
- pin 27 (I2C_SDA) on ATmega328P should connect to pin 13 on MCP23017

#### OLED display

The default QMK firmware enables the OLED display. If not does not work you can check for connectivity between the OLED display and MCP23017. If necessary re-solder the connection.

- pin 9 (Vcc) on the MCP23017 should connect to VCC on the OLED display
- pin 10 (Gnd) on the MCP23017 should connect to GND on the OLED display
- pin 12 (I2C_SCL) on the MCP23017 should connect to SCK/SCL on the OLED display
- pin 13 (I2C_SDA) on the MCP23017 should connect to SDA on the OLED display

When the keyboard is powered check you have 5v between VCC and GND on the OLED display.

You can also visually check the display for damage, especially the surface mounted components under the display.

If the connectivity is good you may need to replace the OLED display.

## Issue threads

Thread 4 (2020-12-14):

Creating a 5x3 Variant

bromanko, 2020-12-14:
I'm very excited about the Torn. It seems to be the best of the Corne with the comfort of a Kyria thumb-cluster. The through-hole components are gorgeous. Kudos on an amazing design.

I'm curious how difficult it would be to make a 5x3 variant. I've never used KiCad before. I'm sure I can remove some components and figure out how to reduce the PCB width. Do you have any tips or suggestions?

rtitmuss, 2020-12-20:
Hi, someone asked about this before and I wasn't sure how easy it would be to route after moving one of the diodes for the thumb keys. However I just had a quick look and it should be pretty easy.

The mounting holes and outline need adjusting still, but it could look something like this:
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

To make this change you would need to update the schematic to remove the switches and diodes, and generate the netlist. Then import the netlist into the pcb designer and reroute the tracks. The Dwgs.User layer has a graphic with the board outline and switch positions. I used that to get the left and right sides (and case parts) to align.

If you decide to try it would be great if you could submit a pull request, and I'd be happy to review.

rtitmuss, 2020-12-20:
Hmm, but after posting the render I think it would be better to layout the diodes in four rows (5, 5, 5, 4). Like this:
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

bromanko, 2020-12-20:
Thanks so much for the feedback! I'll poke at this over the holiday and submit a PR when I have something workable.

bromanko, 2021-01-03:
What do you think of this layout? I still need to learn how to update the routing but wanted to get your feedback before I spent time on it.

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

bromanko, 2021-01-03:
Looks like the lower two left mounting holes will be a problem there. I'm thinking of moving them between the fourth and fifth columns.

rtitmuss, 2021-01-16:
Looks good, as you said the mounting holes need moving. And I've suggested where to put the silk screen labels below:

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

I also checked your diodes placement (D1-D19) and it should be possible to route those. Getting the ordering of the diodes for easy routing was one of the tricker parts of the design :)

I'm guessing it does not make sense for SW5 to have a rotary encoder option with a 5x3 grid, but just wanted to check what you thought.

I've created a discord channel for Torn (https://discord.gg/dy3sCpUj), so feel free to chat there too.

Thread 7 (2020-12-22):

Cover.dxf file has duplicate cut lines

gorbachev, 2020-12-22:
I just put in an order for the acrylic cover with Ponoko, and they're telling me the Cover.dxf contains duplicate cut lines in both top corners. This causes the laser cutter to cut the same location twice, which is likely to cause problems with the end result.

I found out 6 identical lines by converting the DXF file into an SVG using Inkscape, grepping for 'd="m', then sorting them alphabetically. I manually removed them from the SVG file and resubmitted it to Ponoko. Even after that, they're saying there are double lines there.

rtitmuss, 2021-01-02:
Did you find a fix for this? If not I can take a look at this in a week or two.

gorbachev, 2021-01-02:
I did not. I loaded the file to Inkscape, and combined the paths, as recommended as a solution to similar issues on the Internets, but even that didn't remove all the double/overlapping lines according to Ponoko.

My order should be arriving later this week, so I'll find out then if it actually causes any visible issues. Ponoko did manufacture it just fine and they didn't notify me with any issues prior to shipping the order, so I'm assuming it's actually just fine.

bromanko, 2021-01-05:
I pulled the SVGs into Figma and there is a lot of "noise" in the outlines. (See image.) My guess is that these were drawn in KiCad and then exported which didn't produce the cleanest vectors. I'm going to redraw the outline shapes and try to get those cut. If they work I can upload the files.

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

gorbachev, 2021-01-06:
Uh, yea, that doesn't look great.

I just received my order from Ponoko and I can't see anything wrong with the plates they cut for me. This is using an SVG file I saved after I deleted the identical lines from the design. There were overlapping lines still in the file.

rtitmuss, 2021-03-20:
I have uploaded an improved cover.dxf that is cleaner:

https://github.com/rtitmuss/torn/commit/a0d7ace852e73de42067a03e02603ebb7805a3f0

Closed 2021-03-20.

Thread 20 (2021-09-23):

Is the upper plate required for mx switches

raveltan, 2021-09-23:
Hello. I'm new in building keyboard.

Is the upper pcb (where the switches are attached to before in contatct with the main pcb) a required part of the build with mx switches?

rtitmuss, 2021-09-23:
Hi, it is recommended to use a plate of you are using sockets to mount the MX switches. If you are soldering the MX switches then it's optional. The keyboard will feel more stiff/solid with a plate.

zigotica, 2021-09-23:
I would warn against using 3 pin switches without plate, soldered or not, your keys will never be properly aligned.

rtitmuss, 2021-09-24:
Thanks, good advice. I've only used 5 pin switches.

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

raveltan, 2021-09-24:
Ah I see, thanks a lot for the info everybody.

Another question, is the plate required to be in form of pcb, or is it okay if we use other kind of materials (such as acrylics)

rtitmuss, 2021-09-24:
You can use other materials. If you use acrylic I understand that 3mm is
the recommended thickness. I have also used 3d printed and steel plates.

On Fri, Sep 24, 2021 at 7:44 AM Ravel Tan 陈光雄 ***@***.***>
wrote:

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

raveltan, 2021-09-24:
ah okay, thanks a lot for the help

raveltan, 2021-09-25:
sorry everybody, but i have another question, I'm trying to print the plate and bottom plate as acrylic, is there any files in the gerber that contains the length information of the plate (or like file that can be used directly to print the acrylic), or should i do manual measurement of the main pcb?

hahaha sorry if this is a stupid question

keyboard-magpie, 2021-09-25:
There are not currently any laser cutting files- you will have to convert the files [here](https://github.com/rtitmuss/torn/tree/master/case/PCB%20Case)

raveltan, 2021-09-26:
Okay thanks😁

Closed 2021-09-26.

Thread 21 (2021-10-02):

Connection both sides with jumper

raveltan, 2021-10-02:
hello everybody, sorry if this is a stupid question, but because i'm not able to find the specific model of the trrs jack component here in Indonesia, i am wondering if its possible to conect both side of the keyboard using normal jumper wire and some header pins

rtitmuss, 2021-10-02:
Yes you can. For an example see the travel case instructions https://github.com/rtitmuss/torn/tree/master/case/Travel%20Case#step-4.

raveltan, 2021-10-02:
ah okay, thank a lot for the help

Closed 2021-10-02.

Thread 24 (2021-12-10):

Possiblity of using a USBTiny instead of USBasp

repercussion, 2021-12-10:
Hoping you might let me know if it's possible to burn the bootloader and subsequently flash firmwares using USBTiny in lieu of USBasp. Simply replacing the programmer in the makefile.inc will get something burnt, but the pinout in incorrect. Almost everything works, but I can't flash firmwares and a couple switches don't seem to be working.

Very much appreciate it!

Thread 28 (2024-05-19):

Prebuilt Version?

kvnduff, 2024-05-19:
Hi just wanted to check if there is a version for sale anywhere? Noticed that splitkb.com doesn't have anything available yet. I'd be happy to dish out some moola to get this layout. Don't know why there aren't other minimal layouts with four dedicated thumb buttons.

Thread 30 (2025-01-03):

"Left MX top.3mf" Contains "Left Choc top.stl"

repercussion, 2025-01-03:
So in my naivety and not having labels turned on in my slicer, I mistakenly printed the Choc top from the Left MX top.3mf file. Simply replace the "Left Choc top.stl" with the "Left MX top.stl" in the "Left MX top.3mf" file!

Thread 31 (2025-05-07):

Torn doesn't work when connected via keyboard port on KVM

islathehut, 2025-05-07:
I have a [Level1Techs KVM](https://www.store.level1techs.com/products/p/hdmi-21-kvm-wedid-serial-control-dual-monitor-four-computer) and several other QMK keyboards work fine when connected to the keyboard port but my Torn just doesn't.  Occasionally it works for maybe 20 keystrokes before not responding but usually it doesn't even get that far.  I tried following the advice [here](https://forum.level1techs.com/t/kvm-troubles-with-a-qmk-device/184329) but no luck.  Do you have any ideas?

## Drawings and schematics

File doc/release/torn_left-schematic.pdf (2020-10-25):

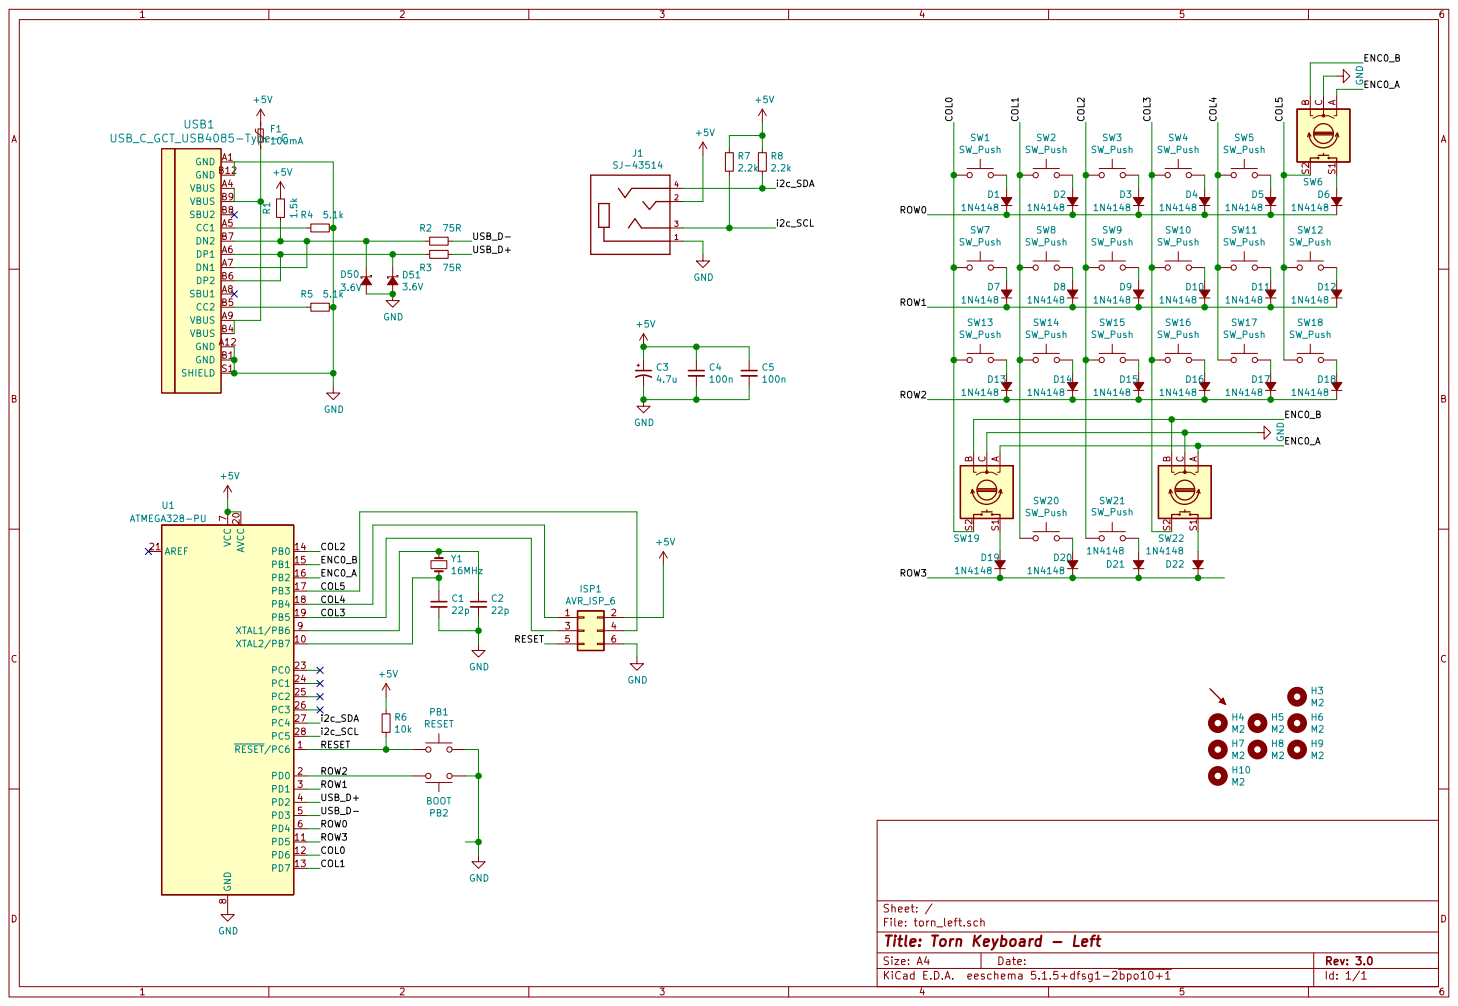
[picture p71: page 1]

File: torn_left.sch Sheet: / GND

Id: 1/1 Title: Torn Keyboard - Left

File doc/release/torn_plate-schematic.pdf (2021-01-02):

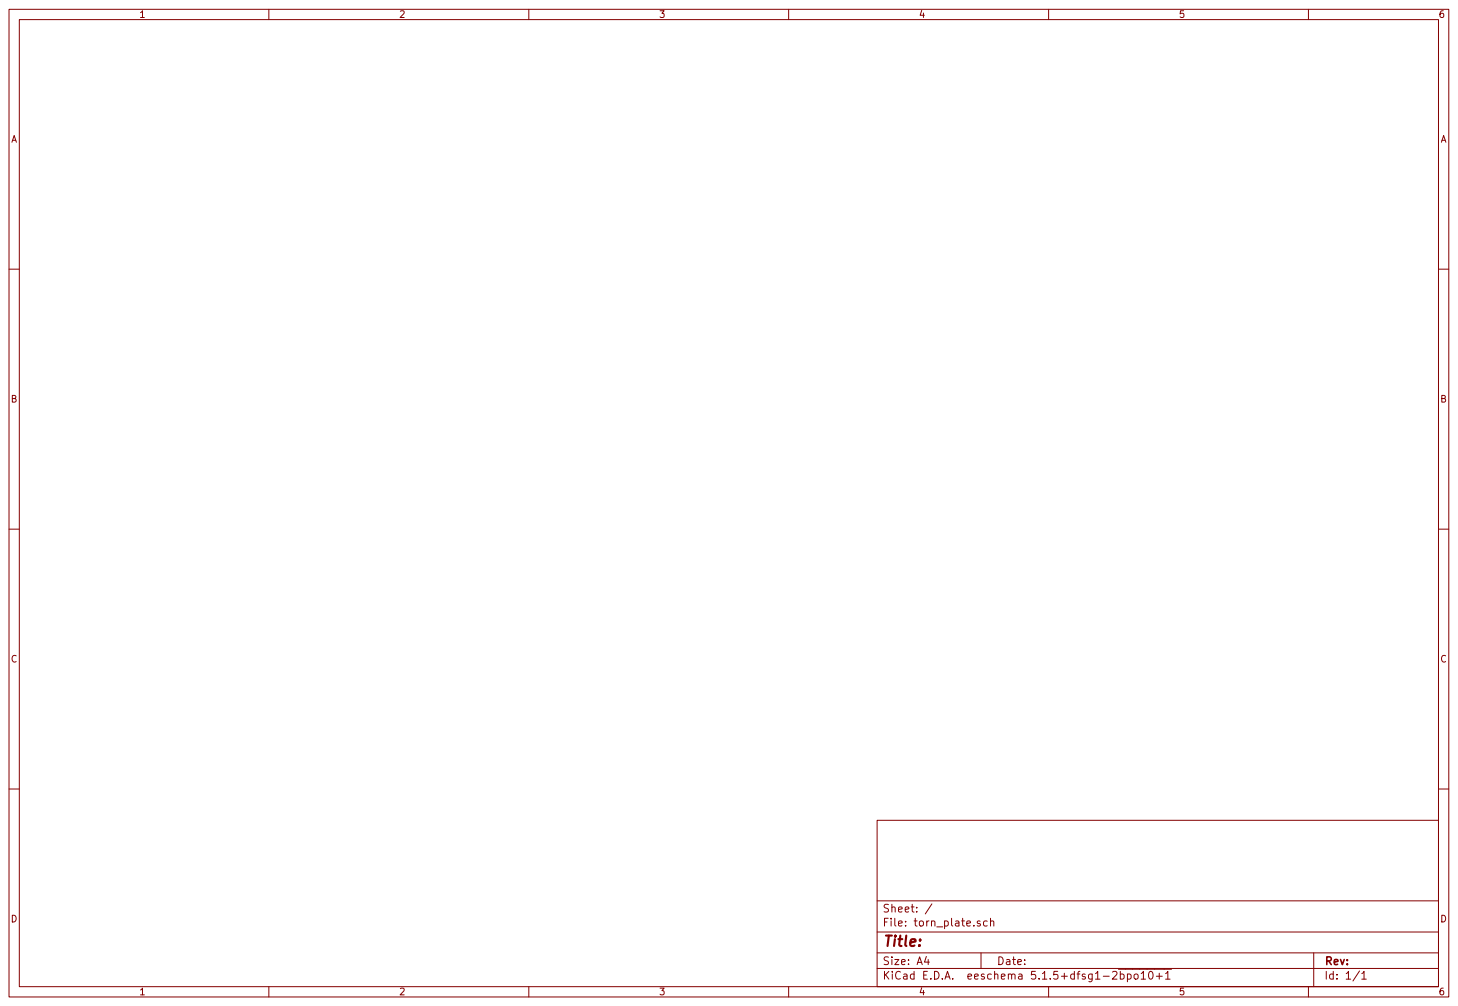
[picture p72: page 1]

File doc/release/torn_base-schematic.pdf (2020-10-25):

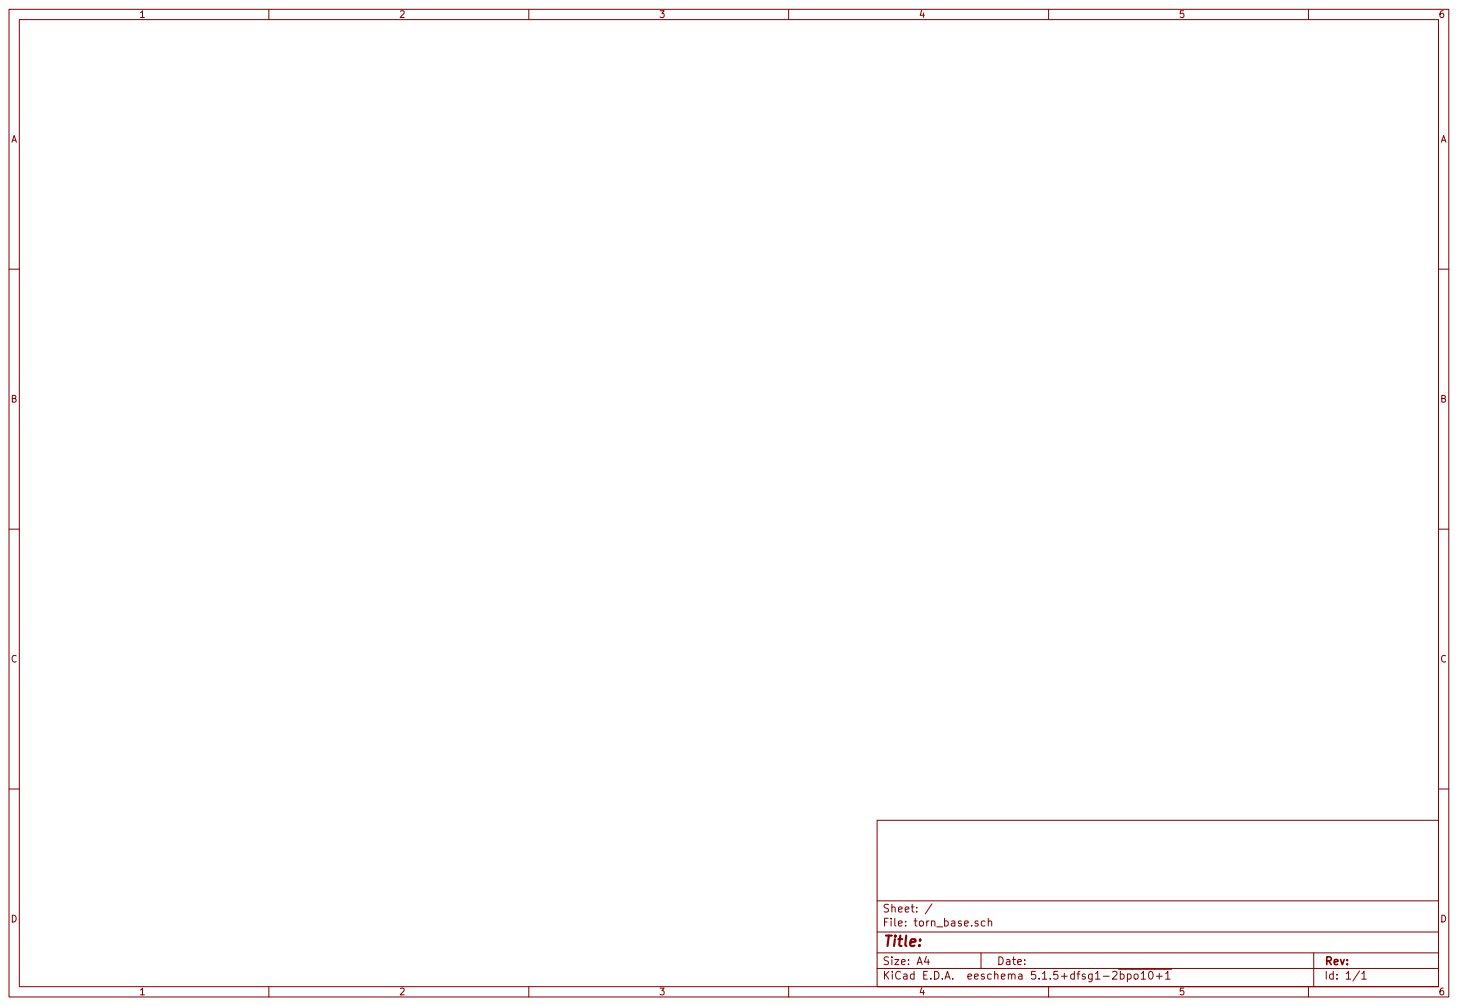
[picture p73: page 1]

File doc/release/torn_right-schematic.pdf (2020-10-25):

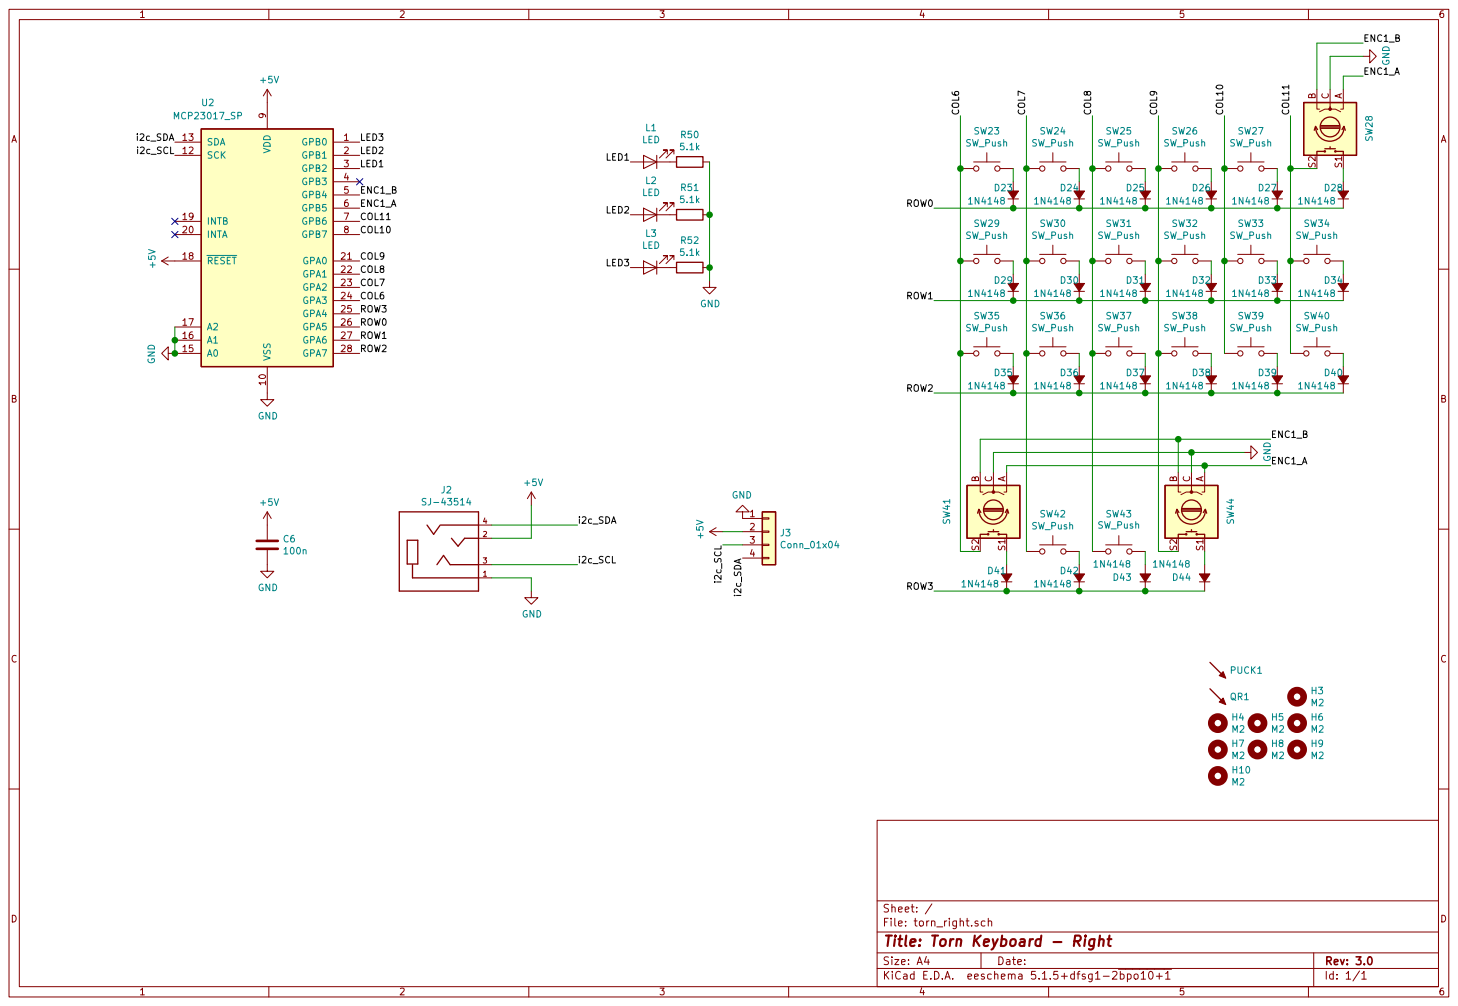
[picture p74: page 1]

File: torn_right.sch Sheet: /
Id: 1/1 Title: Torn Keyboard - Right

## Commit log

2020-08-02 Left pcb
    [torn_left.kicad_pcb, torn_left.sch]
2020-08-02 Right pcb
    [torn_right.kicad_pcb, torn_right.sch]
2020-08-02 Fix trrs connector traces
    In v1 the pcb layout had not been updated after the schematic changes.
    This meant that GND and I2C_SCL were reversed.
    [torn_left.kicad_pcb, torn_left.sch]
2020-08-04 Update the key position and pcb outline
    - Generate a plate using the design from keyboard-layout-editor
    - Fix position of finger keys on right pcb, they were not aligned
    - Slightly adjust the thumb key positions, moving then closer
    - Adjust the board outline based on the new thumb key positions
    - Update the pcb edge cuts
    [outline.dxf, torn_left.kicad_pcb, torn_right.kicad_pcb]
2020-08-04 Switch schematics, moving usb to the left
    [torn_left.sch, torn_right.sch]
2020-08-04 Fix schematic and netlist for switched boards
    - Rename sheets
    - Fix symbol imports
    - Generate and import netlist files
    [torn_left.kicad_pcb, torn_left.sch, torn_right.kicad_pcb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]
2020-08-06 Layout right pcb
    [torn_right.kicad_pcb, torn_right.sch]
2020-08-06 Layout left pcb
    [torn_left.kicad_pcb, torn_left.sch]
2020-08-07 Relayout the diodes
    [torn_left.kicad_pcb, torn_left.sch, torn_right.kicad_pcb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]
2020-08-07 Update plate and pcb outline with 3mm border
    [outline.dxf, torn_left.kicad_pcb, torn_right.kicad_pcb]
2020-08-07 Rotate outer pinky keys
    [torn_left.kicad_pcb, torn_right.kicad_pcb]
2020-08-08 Add vias around key switches
    [torn_left.kicad_pcb, torn_right.kicad_pcb]
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2020-08-08 Update footprint silkscreen
    [torn_left.kicad_pcb, torn_left.sch, torn_right.kicad_pcb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]
2020-08-08 Horizontal fuse and radial cp footprints
    [torn_left.kicad_pcb]
2020-08-09 Improve visual layout of components on left side
    [torn_left.kicad_pcb, torn_right.kicad_pcb]
2020-08-09 Add option for the encoder to be the innermost or outermost thumb key
    ... or you could build with 44 keys and no encoder
    [torn_left.kicad_pcb, torn_left.sch, torn_right.kicad_pcb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]
2020-08-10 Update netlist, bump version ro rev 2.0
    [torn_left.kicad_pcb, torn_right.kicad_pcb]
2020-08-10 Add pcb plate
    [torn-top-plate.kicad_pcb, torn-top-plate.sch]
2020-08-15 Update silkscreen
    [torn-top-plate.kicad_pcb, torn_left.kicad_pcb, torn_right.kicad_pcb]
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2020-08-15 Cleanup tracks and vias
    [torn_left.kicad_pcb, torn_right.kicad_pcb]
2020-08-15 Update silk screen and add pcb renders
    [torn_left.kicad_pcb, torn_right.kicad_pcb]
2020-08-15 Fix plate for jlcpcb
    [torn-top-plate.kicad_pcb]
2020-08-22 Rename for consistency
    [torn_left.kicad_pcb, torn_left.sch, torn_plate.kicad_pcb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]
2020-08-22 Added a release script to generate gerbers, renders etc
2020-08-29 Add base plate
    [torn_base.kicad_pcb, torn_base.sch]
2020-09-01 Fix CC attribution on plate
    [torn_plate.kicad_pcb]
2020-09-01 Add cover
    [cover.dxf]
2020-09-03 Fix symbol references
    [torn_left.sch, torn_right.sch]
2020-09-03 Add support for kailh socket/mx/choc switches
    [torn_left.kicad_pcb, torn_left.sch, torn_right.kicad_pcb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]
2020-09-03 Add support for kailh socket/mx/choc/ec11 switches
    [torn_left.kicad_pcb, torn_left.sch, torn_right.kicad_pcb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]
2020-09-03 Nudge diodes up to clear plate
    [torn_left.kicad_pcb, torn_right.kicad_pcb]
2020-09-04 Move drawings to 50,50
    [torn_base.kicad_pcb, torn_left.kicad_pcb, torn_plate.kicad_pcb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]
2020-09-04 Move thumb mounting holes
    [metal.kicad_pcb, torn_base.kicad_pcb, torn_left.kicad_pcb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]
2020-09-04 Add vias to fill ground plane
    [torn_left.kicad_pcb, torn_right.kicad_pcb]
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2020-09-10 Update cover mounting holes
    [cover.dxf, torn_base.kicad_pcb, torn_left.kicad_pcb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]
2020-09-13 Update led resistor value to reduce brightness
    [torn_right.kicad_pcb, torn_right.sch]
2020-09-13 Refill zones
    [torn_left.kicad_pcb, torn_right.kicad_pcb]
2020-09-20 Add QR code back
    [torn_right.kicad_pcb, torn_right.sch]
2020-09-21 add case files
    [torn-case-v2.stl]
2020-09-24 Right side: version 3, add splitkb tenting puck
    [torn_right.kicad_pcb, torn_right.sch]
2020-09-24 Plate: version 3, add splitkb tenting puck
    [torn_plate.kicad_pcb]
2020-09-24 Left side: version 3, add splitkb tenting puck
    [torn_left.kicad_pcb, torn_left.sch]
2020-09-24 Right side: add encoder option on top right
    [torn_right.kicad_pcb, torn_right.sch]
2020-09-24 Left side: add encoder option on top right
    [torn_left.kicad_pcb, torn_left.sch]
2020-09-24 Nudge switches, holes and edge cuts
    [torn_base.kicad_pcb, torn_left.kicad_pcb, torn_plate.kicad_pcb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]
2020-09-24 Silkscreen updates
    [torn_left.kicad_pcb, torn_right.kicad_pcb]
2020-11-06 Correct USB C soldering incstructions
2020-11-06 Add a note about possible bridges when soldering USB C port
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2021-01-02 Use non-plated holes for the keyswitches in the plate
    The plating could make the holes not square, and the switches could
    bind
    [metal-Dwgs_User.dxf, metal.sch, torn_plate.kicad_pcb]
2021-01-03 Update incorrect Zenner Diode references
    These are marked D50 and D51 on the PCB.
2021-01-03 Fix incorrect resistor value
2021-01-03 Fix colors for 75 ohm resistor
2021-01-16 Update the link to the Torn 2.1 BOM at Octopart
2021-01-23 Refactor case files
    [cover.dxf, metal-Dwgs_User.dxf, metal.kicad_pcb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]
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2021-03-20 Fixed cover dxf
    This is a cleaner drawing from fusion 360 and includes a little
    more space for the keycaps.
    [cover.dxf]
2021-04-19 Update README.md
    Add link to the interactive BOM
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2021-07-03 Add two new 3d printed cases
    [Torn Choc Case Left Base.stl, Torn Choc Case Left Top.stl, Torn Choc Case Right Base.stl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]
2021-07-15 Add HiPro case (#18)
    [EC11 Knob.stl, Left Choc top.3mf, Left Choc top.stl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]
2021-07-16 Add color change for HiPro case logo
    [Left base.3mf, Right base.3mf]
2021-07-29 Update the standoffs in the BOM (#16)
    * Update the standoffs in the BOM
    The previous version worked fine, but this now matches the pictures on the build instructions. With this configuration the parts should work for both the mx and choc builds.
    * Added Kailh Choc plate case standoffs
2021-08-07 Updated stls and guide for travel case
    [Base basic.stl, Base macbook.3mf, Base macbook.stl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]
2021-11-08 Update README.md (#23)
    https://forum.kicad.info/t/warning-avoid-all-links-to-kicad-pcb-org-use-kicad-org/31521
